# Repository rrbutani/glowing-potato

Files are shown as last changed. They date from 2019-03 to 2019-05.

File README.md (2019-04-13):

# glowing-potato

A work in progress. Still needs a name and a README.

##### Group

The group behind this project consists of:
 - [Blake Martini](https://github.com/Dreadzone345)
 - [Sneha Pendharker](https://github.com/spendharkar)
 - [Sameer Mithani](https://github.com/sameermithani)
 - [Rahul Butani](https://github.com/rrbutani)

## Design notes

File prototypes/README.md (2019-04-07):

## Prototypes:

- Clickwheel (ATQ + wheel on FR-4)
- SD Card (microSD Card pin breakout)
- Buttons (push buttons + diodes on a breadboard; ADC + DIN)
- Display (other ILI9314 w/FPC connector on FR-4)
- VS1053 (Adafruit breakout on a breadboard)

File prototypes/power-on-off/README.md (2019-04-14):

# Power On/Off Prototype

Quick test to see if we can combine a NAND Gate based latching power on/power off circuit with a GPIO pin from a microcontroller.

The latching NAND Gate based circuit is the one described on [this page](http://www.mosaic-industries.com/embedded-systems/microcontroller-projects/electronic-circuits/push-button-switch-turn-on/latching-toggle-power-switch) (the "Press ON - Hold OFF latching circuit" in figure 5).

The goal is to use a GPIO pin to force a power off. If we connect an output pin set to low to the capacitor feeding into the NAND gate, we should immediately power off. If this same pin is in a high-Z state, we _should_ (hopefully - this is the assumption being tested) allow the circuit to operate as normal.

GPIO26 doesn't have a reset state listed on the [ESP32 Pin List](https://www.bitsandparts.eu/documentation/484/esp32_chip_pin_list_en.pdf), which supposedly means it'll be in high-Z on reset (according to [this](https://esp32.com/viewtopic.php?t=1926)).

One big flaw in all this is that the circuit runs off unregulated power because it toggles the enable on the regulator instead of the enable pins on all the ICs (why it does this is a separate thing but the short version is that it seems like a safer way to ensure that we aren't drawing much current when powered off - an important thing when using LiPo cells). This means that we can't connect a GPIO pin to the circuit since doing so would expose the ESP32 to higher voltages than it's rated for (>4.2V for a single cell LiPo).

So we'll settle for not truly being able to turn off the device from the ESP32. This is going to result in a weird user interface where we'll expose a software shutdown option which, after performing the necessary software shutdown routines, instructs the user to power and hold the power button to _truly_ shutdown.

Or we can just go into a soft shutdown state (with a button press triggering a 'boot' up) and hope that the other components aren't drawing too much power and that UVLO will save us (now that we have a UVLO circuit this is something that we can actually maybe count on). Sidenote: UVLO should disengage once charging kicks in as we'd expect.

So now that I've written this, it's become apparent that writing this quick and dirty test would be a bad use of time. So, till next time!

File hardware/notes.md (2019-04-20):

things to keep in mind while routing:
- trace width needs to match the current
- our important signal trace pairs should be the same length (use miter)
- silkscreen labels for parts should be small and close to the actual component
- silkscreen things can't overlap vias or pins
- there are minimum via and trace sizes and also minimum distances between things; use the jlcpcb DRU file and run DRC; eagle will check this stuff for you
- some components have particular recommended layouts (@Blake if you don't have time to route, that's fine but can you point me to the suggested layouts/things to check for the crystal, the regulators, and the VS1053?)
- we want to leave a large space from the antenna to the display connector empty so that the battery can go there; traces are fine here and so are low profile components (*<=1mm*)
- nothing on the top of the PCB where the buttons are (unless they're <1mm, but I doubt we'll have anything)
- ATQ traces are sensitive and need to be away from other things
- the antenna is sensitive and needs to have the surrounding ground place stripped away
- nothing on the top layer where the display is other than the traces
- follow the conventions for silkscreen labels (top left anchor for bottom layer parts, text left to right and top to bottom, 90degrees clockwise for vertical labels)
- don't place components in the area directly above the sd card and the headphone jack and in the same places reflected over the middle of the board; we want to leave some space for the magnets (probably 3 by 6mm, 6 vertically)
- don't move the connectors on the bottom (USB, headphone jack, microSD) or the display connector or it's hole or the CP2102N or the antenna or the buttons or the mounting holes around the board. VS1053 should stay roughly where it is and the esp32 and everything else is fair game to move. battery connector I'm thinking should go below the antenna
- turn off measures and document layers to hide all the alignment stuff (don't remove or move anything already on those layers though)
- we have top and bottom ground planes (remind me: *these need to be connected*); use ratsnest to fill them in and ripup to remove them
- using 0402 for resistors and also 0402 for caps *that aren't special*; so far I've only changed the parts on the first page of the schematic
- save early and often; eagle tends to crash with this board, at least for me
- for trace widths: you have to consider how much current will actually go through a particular trace, not just how much current the part you happen to be connecting at that point will draw
- the buttons' footprint is problematic; it has restrict errors which we can fix later
- inductor footprints as of now are misleading and probably should be updated (they take up more space than just their pads)
- I'm thinking either under the display or where the buttons are for silkscreen art
- we can't do via-in-pins or blind/buried via, I think

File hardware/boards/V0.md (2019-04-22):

## V0: Misc things
 - We're going to use 3x1mm disc magnets. These should be thin enough to put underneath the screen.
 - Here are the numbers on the device thickness:
     + We've got our 1.2mm main PCB in the middle. On the top of the device we've got:
         * the display (2.8mm thick); once we add the magnets and the padding (VHB RP45, 1.1mm), we'll get up to 4mm
         * and on the bottom:
             - the buttons (0.56mm)
             - the 3D printer interfacers (0.24mm)
             - the clickwheel PCB (1.2mm)
             - 1/16th inch acrylic (1.5875mm)
             - vinyl (0.4mm, hopefully)
             - for a total of: ~4mm!
         * If all goes according to plan, we should only go 4mm above the top of the top PCB and the 3D printed top half of the case should be flush with the screen and the top of the clickwheel.
     + On the bottom (below the main PCB) we've got a bunch of components. The notable ones are the headphone jack connector and the XH battery connector. The latter is the tallest of the components and clocks in at 6.1mm (a little disappointing since it's the tallest component by a fair margin, but it's fine - it'll give us more headroom for the battery).
         * The bottom casing will need to extend a little bit past this; hopefully no more than 0.9mm or so.
     + This gives us a total thickness of 0.9mm + 6.1mm + 1.2mm + 4mm or 12.2mm which isn't too shabby.

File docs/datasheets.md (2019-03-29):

IC Docs:
 - [AT42QT2120 Datasheet](https://www.mouser.com/datasheet/2/268/doc9634-1369146.pdf)
 - [VS1053 PCB Layout considerations](http://www.vlsi.fi/fileadmin/app_notes/vs10xxan_layout.pdf)
 - [CP2102N Datasheet](https://www.silabs.com/documents/public/data-sheets/cp2102n-datasheet.pdf)
 - [TPS62240 Datasheet](http://www.ti.com/lit/ds/symlink/tps62240.pdf)
 - [TPS63001 Datasheet](http://www.ti.com/lit/ds/symlink/tps63001.pdf)

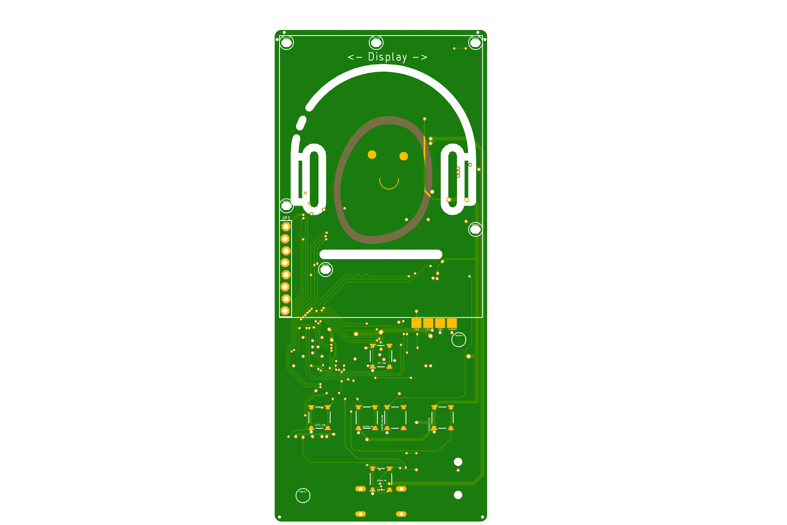
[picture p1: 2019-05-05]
hardware/boards/pico/revA/img/pico-top.png

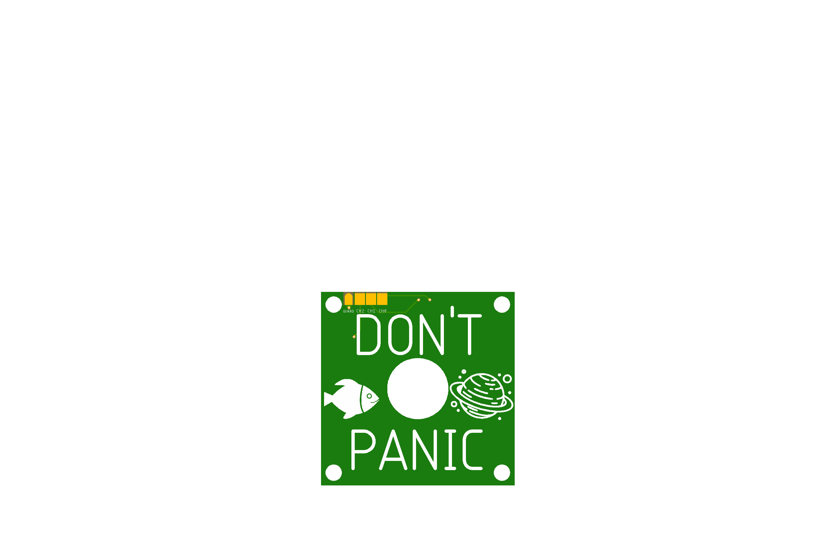
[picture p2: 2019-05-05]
hardware/boards/pico/revA/img/wheel-bottom.png

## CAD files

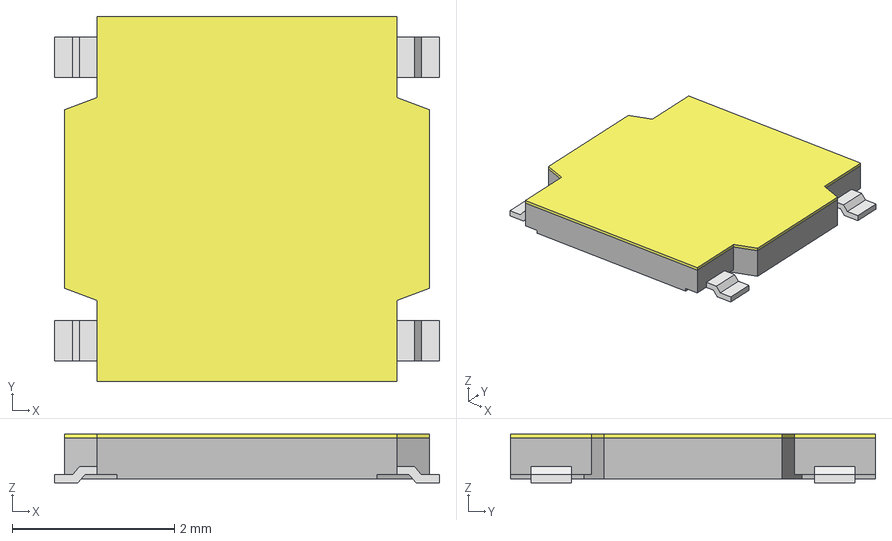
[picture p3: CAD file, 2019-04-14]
hardware/cad/TL3315NF100Q.step
4.75 x 4.50 x 0.6 mm

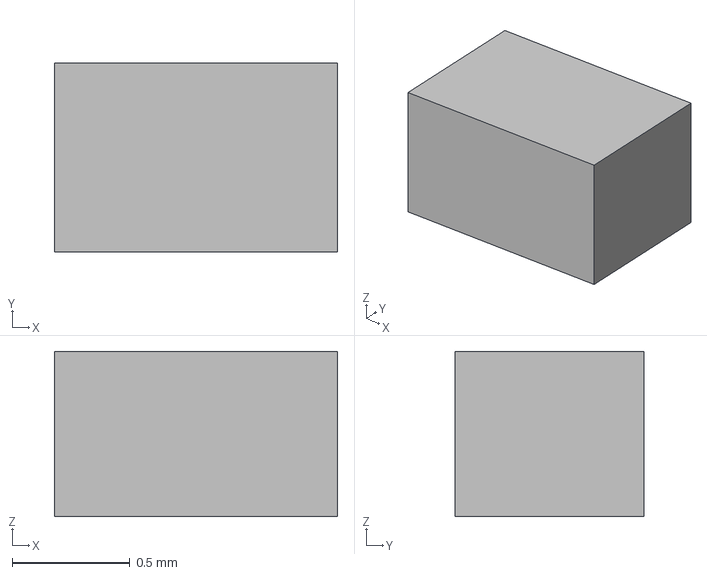
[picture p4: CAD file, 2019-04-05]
hardware/cad/ESD-Diode_On-Semi-ESD5Z5.0T1G.step
1.20 x 0.8 x 0.7 mm

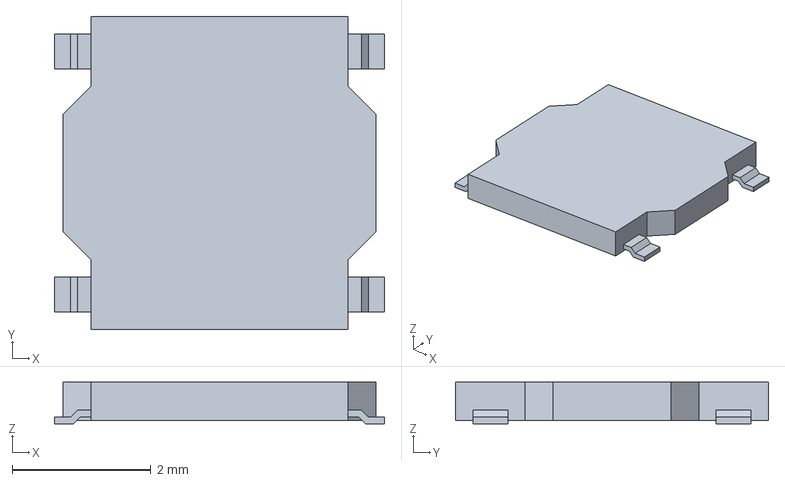
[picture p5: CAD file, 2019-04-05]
hardware/cad/TL3315NF160Q.step
4.75 x 4.50 x 0.6 mm

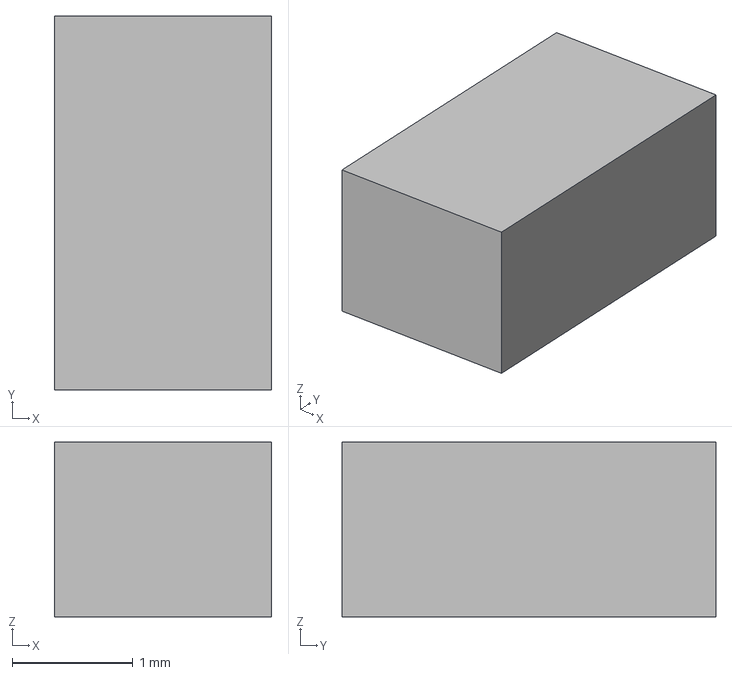
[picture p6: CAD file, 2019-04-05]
hardware/cad/Microchip-MCP73831T-2ATI_2.step
1.80 x 3.10 x 1.45 mm

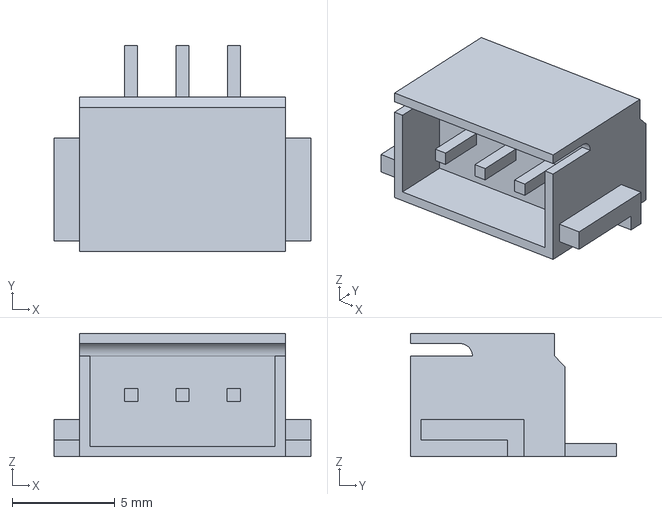
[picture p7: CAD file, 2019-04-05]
hardware/cad/bbf79dea78955795d3a5fd89efec603ff948a89d.step
12.5 x 10.0 x 6.00 mm

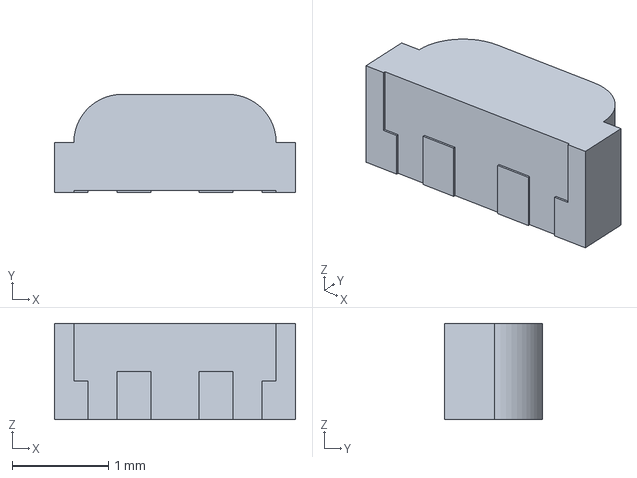
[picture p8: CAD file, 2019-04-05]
hardware/cad/Broadcom-HSMF-C113.step
2.50 x 1.02 x 1.00 mm

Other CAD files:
hardware/cad/Microchip-MCP73831T-2ATI_1.step

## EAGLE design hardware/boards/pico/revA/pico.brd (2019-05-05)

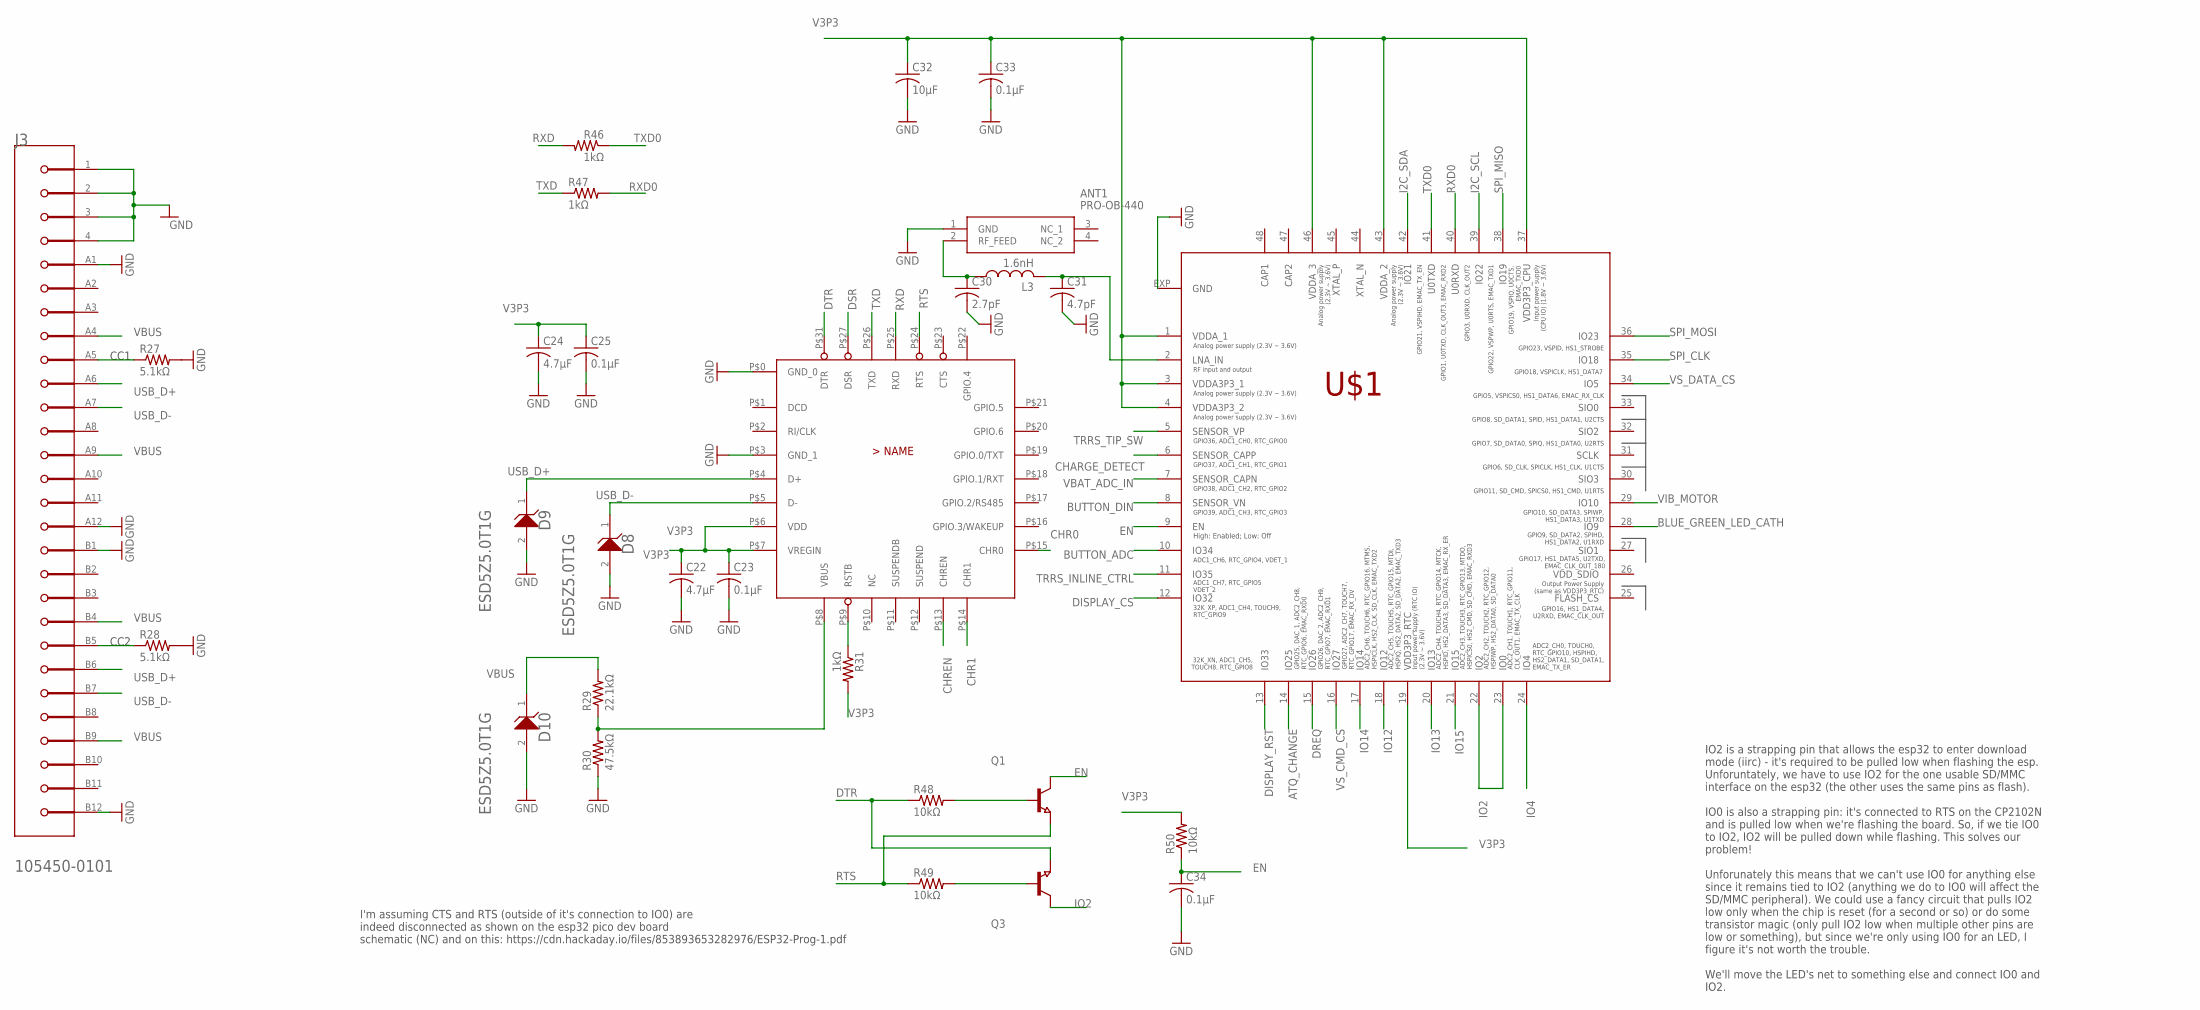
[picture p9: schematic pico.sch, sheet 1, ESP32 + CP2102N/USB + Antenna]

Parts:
ANT1: PRO-OB-440; PRO-OB-440_1
C22, C24: 4.7μF; C0402
C23, C25, C33, C34: 0.1μF; C0402
C30: 2.7pF; C0402
C31: 4.7pF; C0402
C32: 10μF; C0402
D8, D9, D10: ON_SEMICONDUCTOR_ESD5Z5.0T1GON_SEMICONDUCTOR_ESD5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; ON_SEMICONDUCTOR_ESD5Z5.0T1G_0
J3: MOLEX_105450-0101MOLEX_105450-0101_0_0; MOLEX_105450-0101_0
JL: CP2102N-A02-GQFN28; QFN28
L3: 1.6nH; R0402
Q1, Q3: NPN-TRANSISTOR_SOT23; SOT23
R27, R28: 5.1kΩ; R0402
R29: 22.1kΩ; R0402
R30: 47.5kΩ; R0402
R31, R46, R47: 1kΩ; R0402
R48, R49, R50: 10kΩ; R0402
U$1: ESP32-PICO-D4; QFN48

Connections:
ATQ_CHANGE: U$1.14 (IO25); also elsewhere on the board
BLUE_GREEN_LED_CATH: U$1.28 (IO9); also elsewhere on the board
BUTTON_ADC: U$1.10 (IO34); also elsewhere on the board
BUTTON_DIN: U$1.8 (SENSOR_VN); also elsewhere on the board
CHARGE_DETECT: U$1.6 (SENSOR_CAPP); also elsewhere on the board
CHR0: JL.P$15 (CHR0)
CHR1: JL.P$14 (CHR1)
CHREN: JL.P$13 (CHREN)
CP_RSTB: JL.P$9 (RSTB), R31.1
DISPLAY_CS: U$1.12 (IO32); also elsewhere on the board
DISPLAY_RST: U$1.13 (IO33); also elsewhere on the board
DREQ: U$1.15 (IO26); also elsewhere on the board
DSR: JL.P$27 (DSR)
DTR: JL.P$31 (DTR), Q3.2 (E), R48.1
EN: C34.1, Q1.3 (C), R50.1, U$1.9 (EN)
GND: ANT1.1 (GND), C22.2, C23.2, C24.2, C25.2, C30.2, C31.2, C32.2, C33.2, C34.2, D8.2 (A), D9.2 (A), D10.2 (A), J3.1 (MNT_1), J3.2 (MNT_2), J3.3 (MNT_3), J3.4 (MNT_4), J3.A1 (1_GND), J3.A12 (2_GND), J3.B1 (3_GND), J3.B12 (4_GND), JL.P$0 (GND_0), JL.P$3 (GND_1), R27.2, R28.2, R30.1, U$1.EXP (GND); also elsewhere on the board
I2C_SCL: U$1.39 (IO22); also elsewhere on the board
I2C_SDA: U$1.42 (IO21); also elsewhere on the board
IO2: Q3.3 (C), U$1.22 (IO2), U$1.23 (IO0); also elsewhere on the board
IO4: U$1.24 (IO4); also elsewhere on the board
IO12: U$1.18 (IO12); also elsewhere on the board
IO13: U$1.20 (IO13); also elsewhere on the board
IO14: U$1.17 (IO14); also elsewhere on the board
IO15: U$1.21 (IO15); also elsewhere on the board
unnamed: ANT1.2 (RF_FEED), C30.1, L3.1
unnamed: C31.1, L3.2, U$1.2 (LNA_IN)
unnamed: J3.A5 (CC1), R27.1
unnamed: J3.B5 (CC2), R28.1
unnamed: JL.P$8 (VBUS), R29.1, R30.2
unnamed: Q1.1 (B), R48.2
unnamed: Q3.1 (B), R49.2
RTS: JL.P$24 (RTS), Q1.2 (E), R49.1
RXD: JL.P$25 (RXD), R46.2
RXD0: R47.2, U$1.40 (U0RXD)
SPI_CLK: U$1.35 (IO18); also elsewhere on the board
SPI_MISO: U$1.38 (IO19); also elsewhere on the board
SPI_MOSI: U$1.36 (IO23); also elsewhere on the board
TRRS_INLINE_CTRL: U$1.11 (IO35); also elsewhere on the board
TRRS_TIP_SW: U$1.5 (SENSOR_VP); also elsewhere on the board
TXD: JL.P$26 (TXD), R47.1
TXD0: R46.1, U$1.41 (U0TXD)
USB_D+: D9.1 (K), J3.A6 (1_D+), J3.B6 (2_D+), JL.P$4 (D+)
USB_D-: D8.1 (K), J3.A7 (1_D-), J3.B7 (2_D-), JL.P$5 (D-)
V3P3: C22.1, C23.1, C24.1, C25.1, C32.1, C33.1, JL.P$6 (VDD), JL.P$7 (VREGIN), R31.2, R50.2, U$1.1 (VDDA_1), U$1.3 (VDDA3P3_1), U$1.4 (VDDA3P3_2), U$1.19 (VDD3P3_RTC), U$1.37 (VDD3P3_CPU), U$1.43 (VDDA_2), U$1.46 (VDDA_3); also elsewhere on the board
VBAT_ADC_IN: U$1.7 (SENSOR_CAPN); also elsewhere on the board
VBUS: D10.1 (K), J3.A4 (1_VBUS), J3.A9 (2_VBUS), J3.B4 (3_VBUS), J3.B9 (4_VBUS), R29.2; also elsewhere on the board
VIB_MOTOR: U$1.29 (IO10); also elsewhere on the board
VS_CMD_CS: U$1.16 (IO27); also elsewhere on the board
VS_DATA_CS: U$1.34 (IO5); also elsewhere on the board

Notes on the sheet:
CC1
CC2
I'm assuming CTS and RTS (outside of it's connection to IO0) are indeed disconnected as shown on the esp32 pico dev board schematic (NC) and on this: https://cdn.hackaday.io/files/853893653282976/ESP32-Prog-1.pdf
IO2 is a strapping pin that allows the esp32 to enter download mode (iirc) - it's required to be pulled low when flashing the esp. Unforuntately, we have to use IO2 for the one usable SD/MMC interface on the esp32 (the other uses the same pins as flash). IO0 is also a strapping pin: it's connected 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

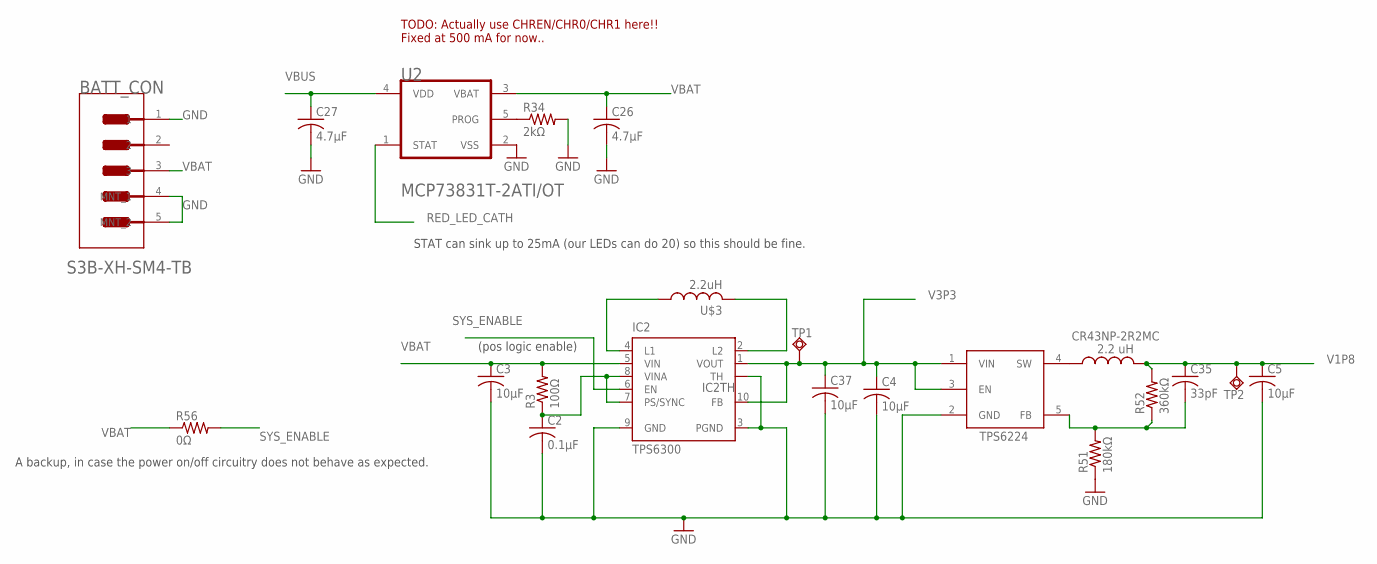
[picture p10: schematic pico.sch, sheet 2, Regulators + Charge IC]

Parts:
BATT_CON: JST_S3B-XH-SM4-TBJST_S3B-XH-SM4-TB_0_0; JST_S3B-XH-SM4-TB_0
C2: 0.1μF; C0402
C3, C4, C5, C37: 10μF; C0402
C26, C27: 4.7μF; C0402
C35: 33pF; C0402
IC2: TPS6300; DRC-S-PVSON-N10
R3: 100Ω; R0402
R34: 2kΩ; R0402
R51: 180kΩ; R0402
R52: 360kΩ; R0402
R56: 0Ω; R0603
TP1, TP2: TPSQTP15SQ; TP15SQ
TPS6224: TPS62240; TSP62240
U2: MICROCHIP_MCP73831T-2ATI-OTMICROCHIP_MCP73831T-2A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; MICROCHIP_MCP73831T-2ATI-OT_1
U$3: 2.2uH; INDUCTOR
U$5: CR43NP-2R2MC; INDUCTOR

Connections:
GND: BATT_CON.1, BATT_CON.4 (MNT_1), BATT_CON.5 (MNT_2), C2.2, C3.2, C4.2, C5.2, C26.2, C27.2, C37.2, IC2.3 (PGND), IC2.9 (GND), IC2.TH, R34.2, R51.1, TPS6224.2 (GND), U2.2 (VSS); also elsewhere on the board
unnamed: C2.1, IC2.7 (PS/SYNC), IC2.8 (VINA), R3.1
unnamed: IC2.2 (L2), U$3.P$2 (2)
unnamed: IC2.4 (L1), U$3.P$1 (1)
unnamed: TPS6224.4 (SW), U$5.P$1 (1)
unnamed: C35.2, R51.2, R52.1, TPS6224.5 (FB)
unnamed: R34.1, U2.5 (PROG)
RED_LED_CATH: U2.1 (STAT); also elsewhere on the board
SYS_ENABLE: IC2.6 (EN), R56.2; also elsewhere on the board
V1P8: C5.1, C35.1, R52.2, TP2.TP, U$5.P$2 (2); also elsewhere on the board
V3P3: C4.1, C37.1, IC2.1 (VOUT), IC2.10 (FB), TP1.TP, TPS6224.1 (VIN), TPS6224.3 (EN); also elsewhere on the board
VBAT: BATT_CON.3, C3.1, C26.1, IC2.5 (VIN), R3.2, R56.1, U2.3 (VBAT); also elsewhere on the board
VBUS: C27.1, U2.4 (VDD); also elsewhere on the board

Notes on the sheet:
TPS6224
TODO: Actually use CHREN/CHR0/CHR1 here!! Fixed at 500 mA for now..
STAT can sink up to 25mA (our LEDs can do 20) so this should be fine.
(pos logic enable)
A backup, in case the power on/off circuitry does not behave as expected.

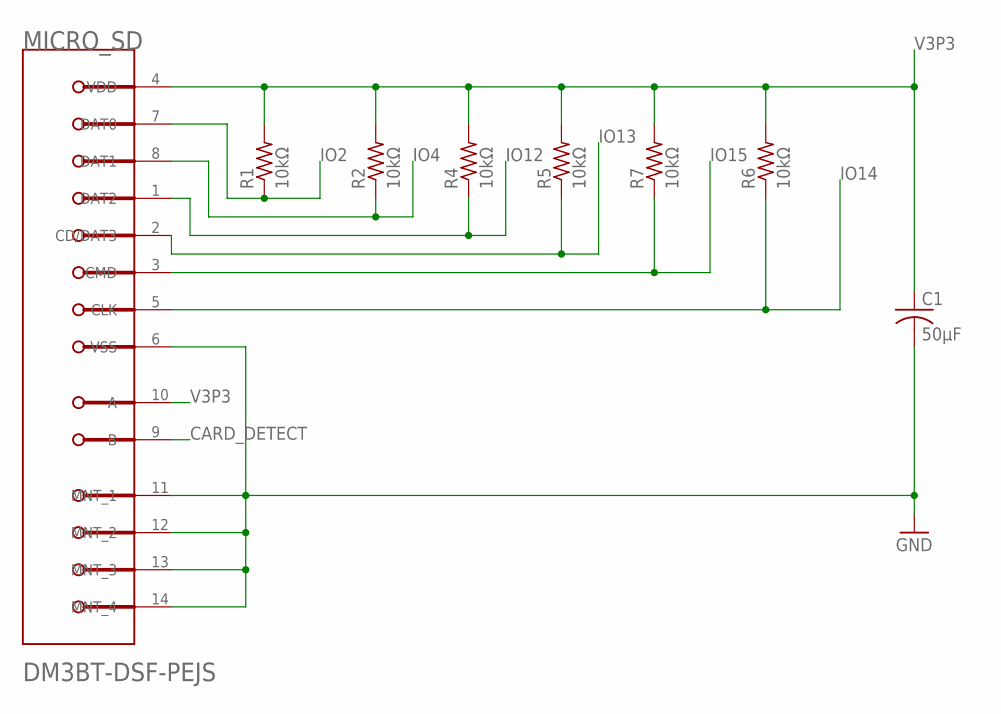
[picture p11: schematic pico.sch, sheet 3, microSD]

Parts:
C1: 50μF; C0402
MICRO_SD: HIROSE_DM3BT-DSF-PEJSHIROSE_DM3BT-DSF-PEJS_0_0; HIROSE_DM3BT-DSF-PEJS_0
R1, R2, R4, R5, R6, R7: 10kΩ; R0402

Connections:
CARD_DETECT: MICRO_SD.9 (B); also elsewhere on the board
GND: C1.2, MICRO_SD.6 (VSS), MICRO_SD.11 (MNT_1), MICRO_SD.12 (MNT_2), MICRO_SD.13 (MNT_3), MICRO_SD.14 (MNT_4); also elsewhere on the board
IO2: MICRO_SD.7 (DAT0), R1.1; also elsewhere on the board
IO4: MICRO_SD.8 (DAT1), R2.1; also elsewhere on the board
IO12: MICRO_SD.1 (DAT2), R4.1; also elsewhere on the board
IO13: MICRO_SD.2 (CD/DAT3), R5.1; also elsewhere on the board
IO14: MICRO_SD.5 (CLK), R6.1; also elsewhere on the board
IO15: MICRO_SD.3 (CMD), R7.1; also elsewhere on the board
V3P3: C1.1, MICRO_SD.4 (VDD), MICRO_SD.10 (A), R1.2, R2.2, R4.2, R5.2, R6.2, R7.2; also elsewhere on the board

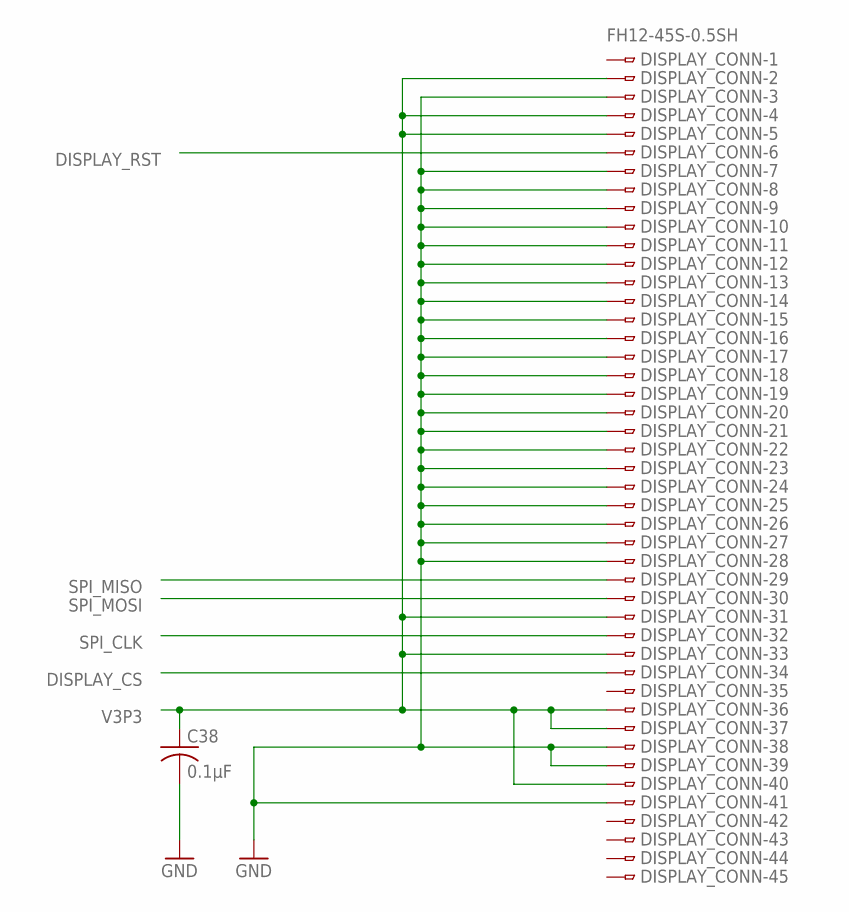
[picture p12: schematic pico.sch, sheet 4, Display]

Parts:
C38: 0.1μF; C0402
DISPLAY_CONN: FH12-45S-0.5SH

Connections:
DISPLAY_CS: DISPLAY_CONN.34; also elsewhere on the board
DISPLAY_RST: DISPLAY_CONN.6; also elsewhere on the board
GND: C38.2, DISPLAY_CONN.3, DISPLAY_CONN.7, DISPLAY_CONN.8, DISPLAY_CONN.9, DISPLAY_CONN.10, DISPLAY_CONN.11, DISPLAY_CONN.12, DISPLAY_CONN.13, DISPLAY_CONN.14, DISPLAY_CONN.15, DISPLAY_CONN.16, DISPLAY_CONN.17, DISPLAY_CONN.18, DISPLAY_CONN.19, DISPLAY_CONN.20, DISPLAY_CONN.21, DISPLAY_CONN.22, DISPLAY_CONN.23, DISPLAY_CONN.24, DISPLAY_CONN.25, DISPLAY_CONN.26, DISPLAY_CONN.27, DISPLAY_CONN.28, DISPLAY_CONN.38, DISPLAY_CONN.39, DISPLAY_CONN.41; also elsewhere on the board
SPI_CLK: DISPLAY_CONN.32; also elsewhere on the board
SPI_MISO: DISPLAY_CONN.29; also elsewhere on the board
SPI_MOSI: DISPLAY_CONN.30; also elsewhere on the board
V3P3: C38.1, DISPLAY_CONN.2, DISPLAY_CONN.4, DISPLAY_CONN.5, DISPLAY_CONN.31, DISPLAY_CONN.33, DISPLAY_CONN.36, DISPLAY_CONN.37, DISPLAY_CONN.40; also elsewhere on the board

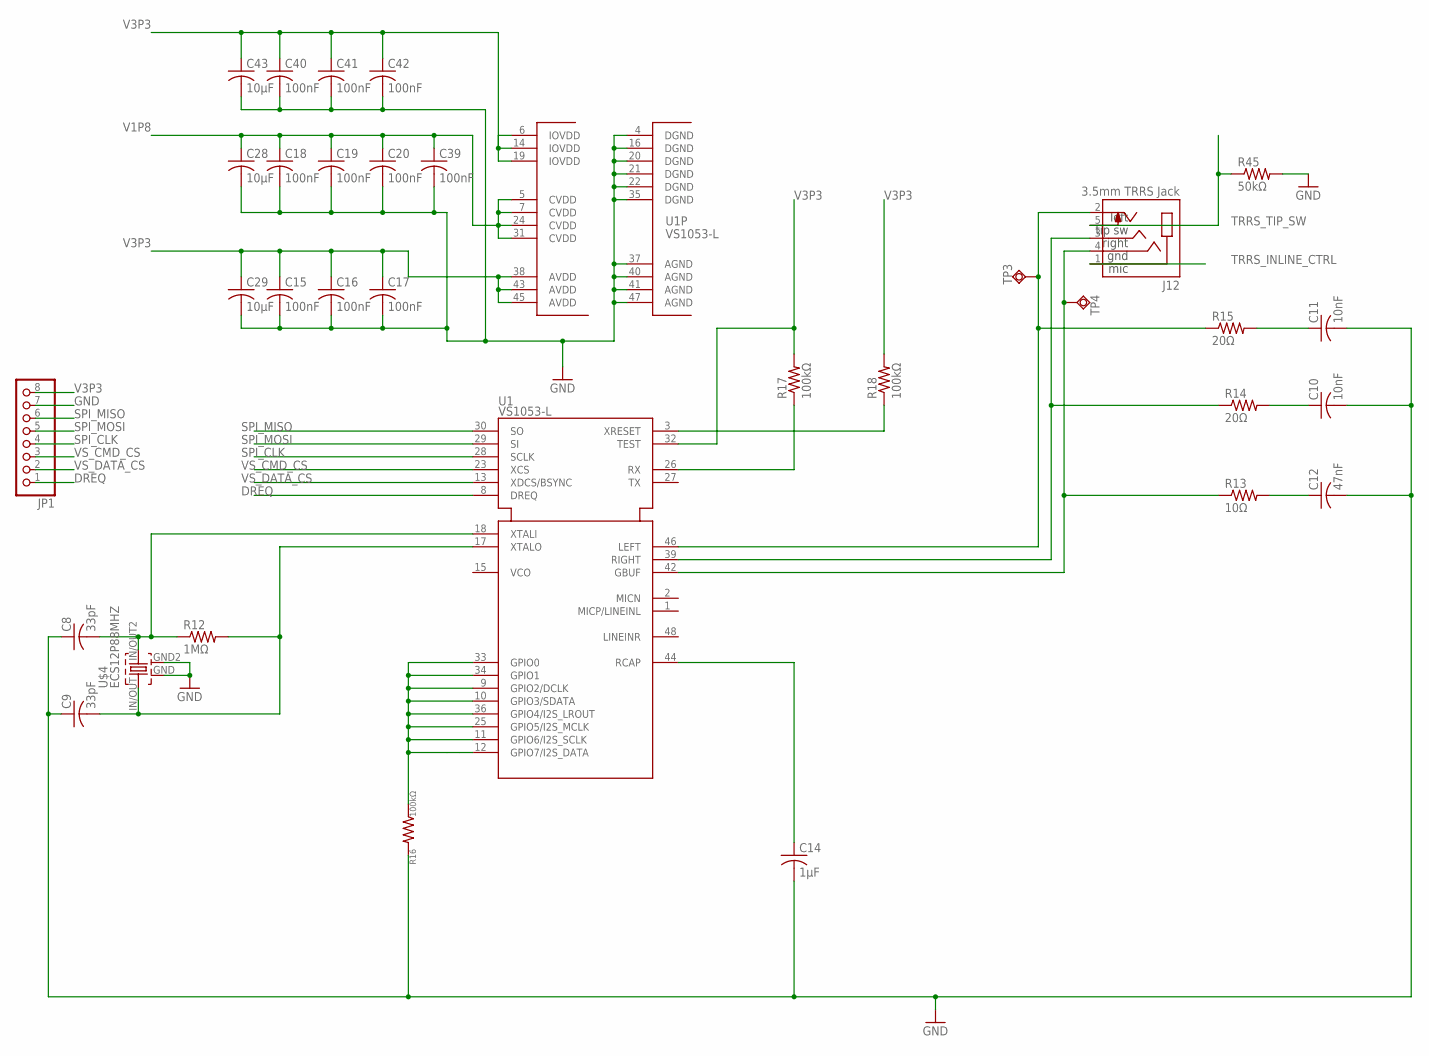
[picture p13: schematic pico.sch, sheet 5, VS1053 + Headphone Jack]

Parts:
C8, C9: 33pF; C0402
C10, C11: 10nF; C0402
C12: 47nF; C0402
C14: 1μF; C0402
C15, C16, C17, C18, C19, C20, C39, C40, C41, C42: 100nF; C0402
C28, C29, C43: 10μF; C0402
J12: 3.5mm TRRS Jack; CUI_SJ-43515TS-SMT
JP1: PINHD-1X8LOCK; 1X08-LOCK
R12: 1MΩ; R0402
R13: 10Ω; R0402
R14, R15: 20Ω; R0402
R16, R17, R18: 100kΩ; R0402
R45: 50kΩ; R0402
TP3, TP4: TPSQTP15SQ; TP15SQ
U1: VS1053-L; LQFP48
U$4: ECS12P88MHZ; ECSCRYSTAL

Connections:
DREQ: JP1.1, U1.8 (DREQ); also elsewhere on the board
GND: C8.1, C9.1, C10.2, C11.2, C12.2, C14.2, C15.2, C16.2, C17.2, C18.2, C19.2, C20.2, C28.2, C29.2, C39.2, C40.2, C41.2, C42.2, C43.2, JP1.7, R16.2, R45.2, U1.4 (DGND), U1.16 (DGND), U1.20 (DGND), U1.21 (DGND), U1.22 (DGND), U1.35 (DGND), U1.37 (AGND), U1.40 (AGND), U1.41 (AGND), U1.47 (AGND), U$4.GND, U$4.GND2; also elsewhere on the board
unnamed: C8.2, R12.1, U1.18 (XTALI), U$4.IN/OUT2
unnamed: C9.2, R12.2, U1.17 (XTALO), U$4.IN/OUT
unnamed: R17.1, U1.26 (RX)
unnamed: C12.1, R13.2
unnamed: C10.1, R14.2
unnamed: C11.1, R15.2
unnamed: C14.1, U1.44 (RCAP)
unnamed: R18.1, U1.3 (XRESET)
unnamed: R16.1, U1.9 (GPIO2/DCLK), U1.10 (GPIO3/SDATA), U1.11 (GPIO6/I2S_SCLK), U1.12 (GPIO7/I2S_DATA), U1.25 (GPIO5/I2S_MCLK), U1.33 (GPIO0), U1.34 (GPIO1), U1.36 (GPIO4/I2S_LROUT)
unnamed: J12.4 (RING2), R13.1, TP4.TP, U1.42 (GBUF)
unnamed: J12.3 (RING1), R14.1, U1.39 (RIGHT)
unnamed: J12.2 (TIP), R15.1, TP3.TP, U1.46 (LEFT)
SPI_CLK: JP1.4, U1.28 (SCLK); also elsewhere on the board
SPI_MISO: JP1.6, U1.30 (SO); also elsewhere on the board
SPI_MOSI: JP1.5, U1.29 (SI); also elsewhere on the board
TRRS_INLINE_CTRL: J12.1 (SLEEVE); also elsewhere on the board
TRRS_TIP_SW: J12.5 (TIP_SWITCH), R45.1; also elsewhere on the board
V1P8: C18.1, C19.1, C20.1, C28.1, C39.1, U1.5 (CVDD), U1.7 (CVDD), U1.24 (CVDD), U1.31 (CVDD); also elsewhere on the board
V3P3: C15.1, C16.1, C17.1, C29.1, C40.1, C41.1, C42.1, C43.1, JP1.8, R17.2, R18.2, U1.6 (IOVDD), U1.14 (IOVDD), U1.19 (IOVDD), U1.32 (TEST), U1.38 (AVDD), U1.43 (AVDD), U1.45 (AVDD); also elsewhere on the board
VS_CMD_CS: JP1.3, U1.23 (XCS); also elsewhere on the board
VS_DATA_CS: JP1.2, U1.13 (XDCS/BSYNC); also elsewhere on the board

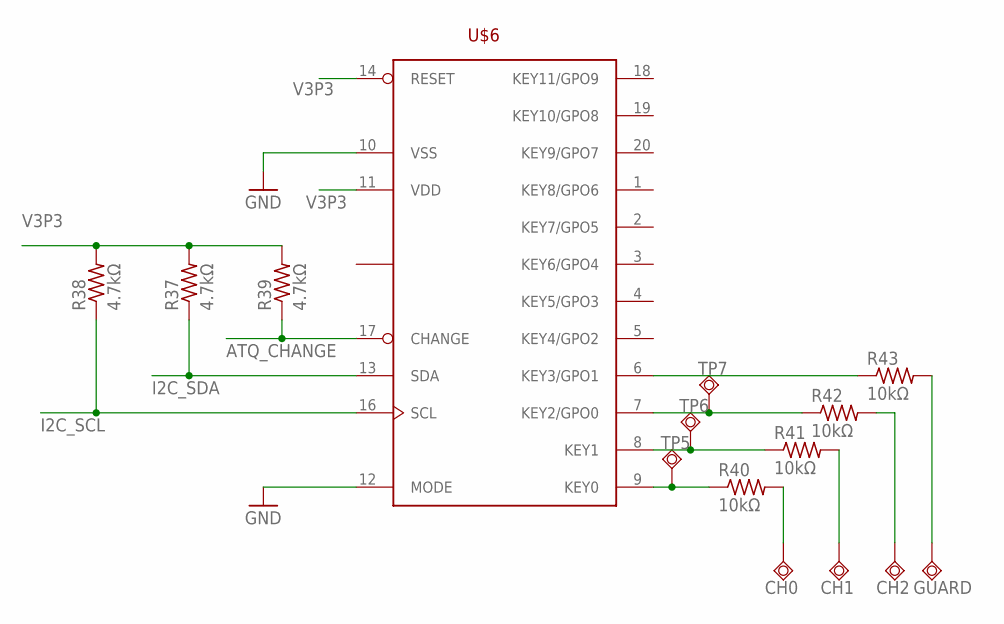
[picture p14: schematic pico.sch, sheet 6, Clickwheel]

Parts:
CH0, CH1, CH2: TPSQTP20SQ; TP20SQ
GUARD: TPSQTP20SQ; TP20SQ
R37, R38, R39: 4.7kΩ; R0402
R40, R41, R42, R43: 10kΩ; R0402
TP5, TP6, TP7: TPSQTP15SQ; TP15SQ
U$6: COMMS-AT42QT2120XU; TSSOP20

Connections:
ATQ_CHANGE: R39.1, U$6.17 (CHANGE); also elsewhere on the board
GND: U$6.10 (VSS), U$6.12 (MODE); also elsewhere on the board
I2C_SCL: R38.1, U$6.16 (SCL); also elsewhere on the board
I2C_SDA: R37.1, U$6.13 (SDA); also elsewhere on the board
unnamed: R40.1, TP5.TP, U$6.9 (KEY0)
unnamed: CH1.TP, R41.2
unnamed: CH2.TP, R42.2
unnamed: R41.1, TP6.TP, U$6.8 (KEY1)
unnamed: R42.1, TP7.TP, U$6.7 (KEY2/GPO0)
unnamed: R43.1, U$6.6 (KEY3/GPO1)
unnamed: CH0.TP, R40.2
unnamed: GUARD.TP, R43.2
V3P3: R37.2, R38.2, R39.2, U$6.11 (VDD), U$6.14 (RESET); also elsewhere on the board

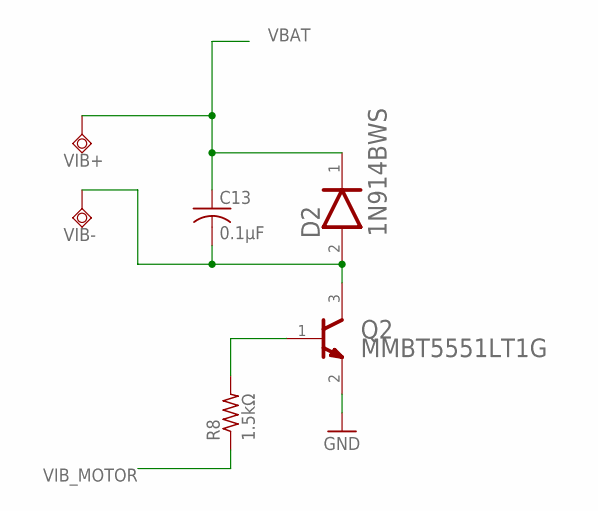
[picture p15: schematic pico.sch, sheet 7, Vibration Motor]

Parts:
C13: 0.1μF; C0402
D2: ON_SEMI_1N914BWSON_SEMI_1N914BWS_0_0; ON_SEMI_1N914BWS_0
Q2: ON_SEMI_MMBT5551LT1GON_SEMI_MMBT5551LT1G_0_0; ON_SEMI_MMBT5551LT1G_0
R8: 1.5kΩ; R0402
VIB+: TPSQTP20SQ; TP20SQ
VIB-: TPSQTP20SQ; TP20SQ

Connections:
GND: Q2.2 (EMITTER); also elsewhere on the board
unnamed: C13.2, D2.2 (ANODE), Q2.3 (COLLECTOR), VIB-.TP
unnamed: Q2.1 (BASE), R8.2
VBAT: C13.1, D2.1 (CATHODE), VIB+.TP; also elsewhere on the board
VIB_MOTOR: R8.1; also elsewhere on the board

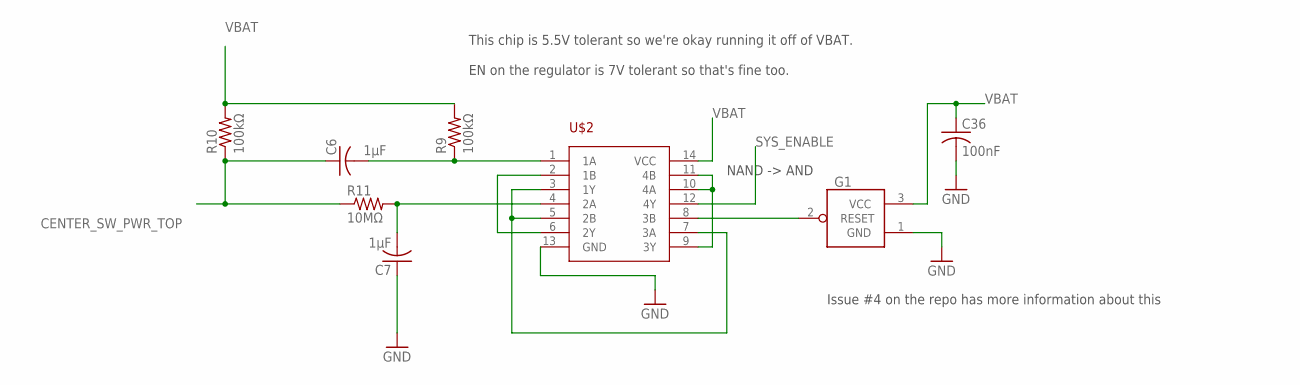
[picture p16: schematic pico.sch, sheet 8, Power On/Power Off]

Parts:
C6, C7: 1μF; C0402
C36: 100nF; C0402
G1: APX809S-31SA; SOT23
R9, R10: 100kΩ; R0402
R11: 10MΩ; R0402
U$2: TOSHIBA-NAND-GATE; TSSOP14

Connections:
CENTER_SW_PWR_TOP: C6.1, R10.1, R11.1; also elsewhere on the board
GND: C7.1, C36.2, G1.1 (GND), U$2.13 (GND); also elsewhere on the board
unnamed: C6.2, R9.1, U$2.1 (1A)
unnamed: U$2.3 (1Y), U$2.5 (2B), U$2.7 (3A)
unnamed: C7.2, R11.2, U$2.4 (2A)
unnamed: U$2.2 (1B), U$2.6 (2Y)
unnamed: U$2.9 (3Y), U$2.10 (4A), U$2.11 (4B)
unnamed: G1.2 (RESET), U$2.8 (3B)
SYS_ENABLE: U$2.12 (4Y); also elsewhere on the board
VBAT: C36.1, G1.3 (VCC), R9.2, R10.2, U$2.14 (VCC); also elsewhere on the board

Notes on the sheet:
This chip is 5.5V tolerant so we're okay running it off of VBAT. EN on the regulator is 7V tolerant so that's fine too.
Issue #4 on the repo has more information about this
NAND -> AND

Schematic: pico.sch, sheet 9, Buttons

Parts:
C21: 0.1μF; C0402
CENTER_SW: E-SWITCH_TL3315NF100QE-SWITCH_TL3315NF100Q_0_0; E-SWITCH_TL3315NF100Q_0
CENTER_SW_PWR: E-SWITCH_TL3315NF100QE-SWITCH_TL3315NF100Q_0_0; E-SWITCH_TL3315NF100Q_0
D3, D4, D5, D6, D7: DIODESOD-523; SOD-523
DOWN_SW: E-SWITCH_TL3315NF160QE-SWITCH_TL3315NF160Q_0_0; E-SWITCH_TL3315NF160Q_0
LEFT_SW: E-SWITCH_TL3315NF160QE-SWITCH_TL3315NF160Q_0_0; E-SWITCH_TL3315NF160Q_0
R19: 155kΩ; R0402
R20: 75kΩ; R0402
R21: 35kΩ; R0402
R22: 15kΩ; R0402
R23, R25: 5kΩ; R0402
R24: 50kΩ; R0402
R26: 10kΩ; R0402
R54: 315kΩ; R0402
RIGHT_SW: E-SWITCH_TL3315NF160QE-SWITCH_TL3315NF160Q_0_0; E-SWITCH_TL3315NF160Q_0
UP_SW: E-SWITCH_TL3315NF160QE-SWITCH_TL3315NF160Q_0_0; E-SWITCH_TL3315NF160Q_0

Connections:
BUTTON_ADC: R19.1, R20.1, R21.1, R22.1, R23.1, R25.2, R54.1; also elsewhere on the board
BUTTON_DIN: C21.2, R24.2; also elsewhere on the board
CARD_DETECT: R54.2; also elsewhere on the board
CENTER_SW_PWR_TOP: CENTER_SW_PWR.1, CENTER_SW_PWR.1-2 (1), CENTER_SW_PWR.2, CENTER_SW_PWR.2-2 (2); also elsewhere on the board
GND: CENTER_SW_PWR.3, CENTER_SW_PWR.3-2 (3), CENTER_SW_PWR.4, CENTER_SW_PWR.4-2 (4), R25.1, R26.1; also elsewhere on the board
unnamed: D4.A, R20.2, UP_SW.3, UP_SW.3-2 (3), UP_SW.4, UP_SW.4-2 (4)
unnamed: D5.A, R21.2, RIGHT_SW.3, RIGHT_SW.3-2 (3), RIGHT_SW.4, RIGHT_SW.4-2 (4)
unnamed: D6.A, DOWN_SW.3, DOWN_SW.3-2 (3), DOWN_SW.4, DOWN_SW.4-2 (4), R22.2
unnamed: CENTER_SW.3, CENTER_SW.3-2 (3), CENTER_SW.4, CENTER_SW.4-2 (4), D7.A, R23.2
unnamed: D3.K (C), D4.K (C), D5.K (C), D6.K (C), D7.K (C), R24.1, R26.2
unnamed: D3.A, LEFT_SW.3, LEFT_SW.3-2 (3), LEFT_SW.4, LEFT_SW.4-2 (4), R19.2
V3P3: C21.1, CENTER_SW.1, CENTER_SW.1-2 (1), CENTER_SW.2, CENTER_SW.2-2 (2), DOWN_SW.1, DOWN_SW.1-2 (1), DOWN_SW.2, DOWN_SW.2-2 (2), LEFT_SW.1, LEFT_SW.1-2 (1), LEFT_SW.2, LEFT_SW.2-2 (2), RIGHT_SW.1, RIGHT_SW.1-2 (1), RIGHT_SW.2, RIGHT_SW.2-2 (2), UP_SW.1, UP_SW.1-2 (1), UP_SW.2, UP_SW.2-2 (2); also elsewhere on the board

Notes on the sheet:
We're going to cheat and introduce a second center switch. It's not optimal but it's a lot less risky than hooking up the real center button to VBAT and hoping that the diode brings the voltage down to spec.

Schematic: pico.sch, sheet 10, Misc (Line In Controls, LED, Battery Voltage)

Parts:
D1: BROADCOM_HSMF-C113BROADCOM_HSMF-C113_0_0; BROADCOM_HSMF-C113_0
R32, R44, R53: 10kΩ; R0402
R33: 5kΩ; R0402
R35: 100Ω; R0402
R36: 50Ω; R0402
R55: 25Ω; R0402

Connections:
BLUE_GREEN_LED_CATH: R36.2, R55.2; also elsewhere on the board
CHARGE_DETECT: R53.1; also elsewhere on the board
GND: R32.1; also elsewhere on the board
unnamed: D1.1 (BLUE_CATHODE), R55.1
unnamed: D1.3 (RED_CATHODE), R35.1
unnamed: D1.4 (GREEN_CATHODE), R36.1
RED_LED_CATH: R35.2, R53.2; also elsewhere on the board
TRRS_INLINE_CTRL: R44.1; also elsewhere on the board
V3P3: D1.2 (COMMON_ANODE), R44.2; also elsewhere on the board
VBAT: R33.2; also elsewhere on the board
VBAT_ADC_IN: R32.2, R33.1; also elsewhere on the board

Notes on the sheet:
Red LED has a 1.9V drop and 20mA, so: 1.4V for 20mA = V / I = R = 1.4V / 20mA = 70 ohms since we don't want to blind people let's call it an even 100
Green LED (AlInGaP Green on the C113) has a drop of about 2.3 volts also on about 20mA. 1.0 volts for 20mA = V / I = R = 1 / 20mA = 50 ohms
Blue has a voltage drop of ~3.7V which is greater than our regulated voltage so we won't bother with a current limiting resistor. Actually we'll add one to protect the esp.
I'm not sure this will work, so leave this resistor off initially/until we've thought it through.
(resistor value here is a guess)

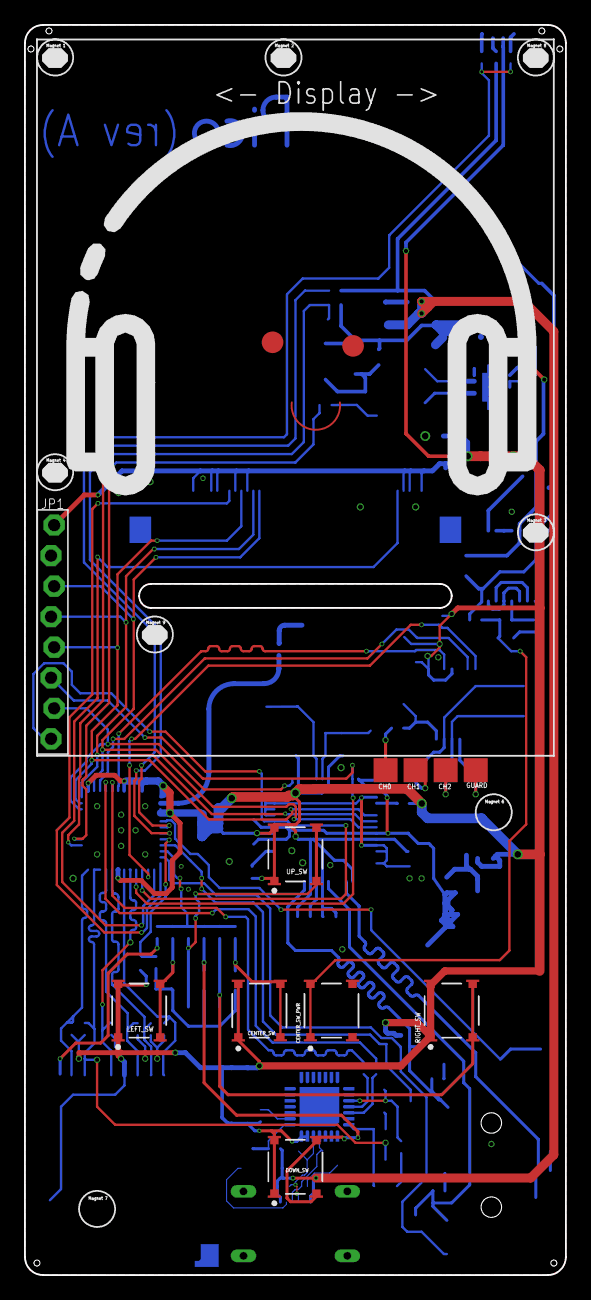
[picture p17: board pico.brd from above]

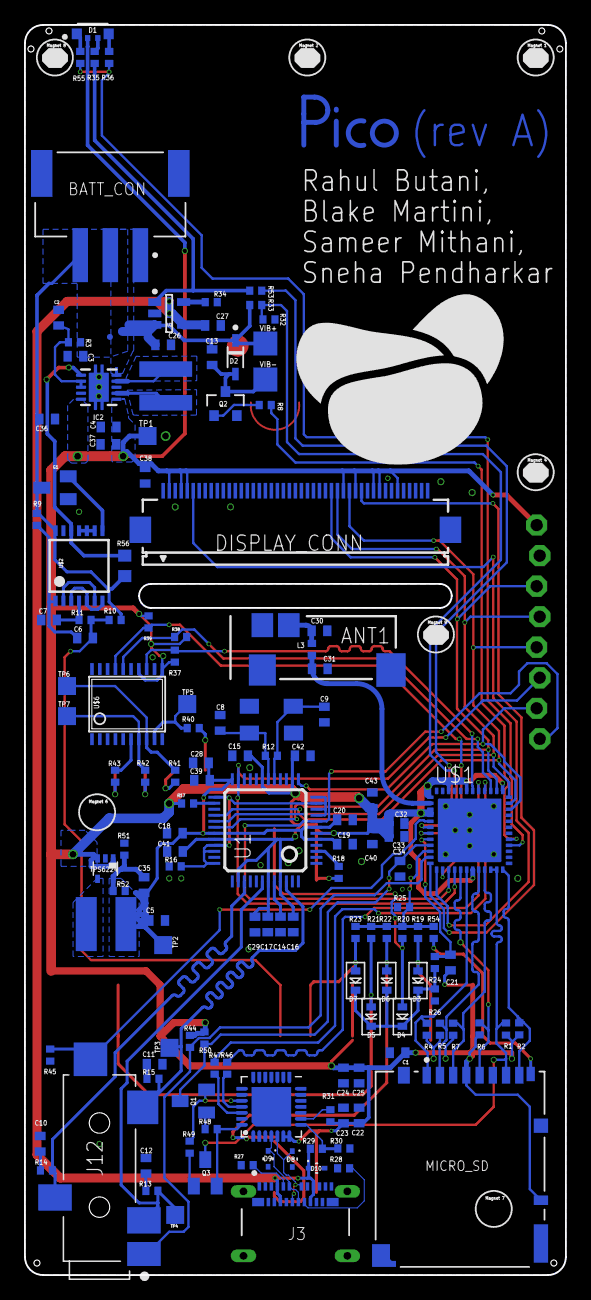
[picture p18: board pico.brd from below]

Board: 2 copper layers, 45.0 x 104.0 mm, 151 parts (140 on the bottom side), 94 nets.

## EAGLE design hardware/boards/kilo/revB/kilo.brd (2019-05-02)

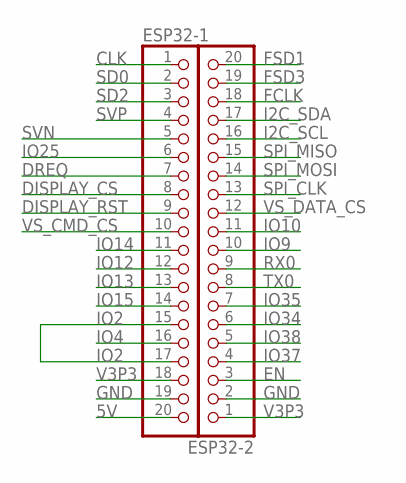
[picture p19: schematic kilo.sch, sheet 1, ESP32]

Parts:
ESP32-1, ESP32-2: PINHD-1X20; 1X20

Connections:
5V: ESP32-1.20
CLK: ESP32-1.1
DISPLAY_CS: ESP32-1.8; also elsewhere on the board
DISPLAY_RST: ESP32-1.9; also elsewhere on the board
DREQ: ESP32-1.7; also elsewhere on the board
EN: ESP32-2.3
FCLK: ESP32-2.18
FSD1: ESP32-2.20
FSD3: ESP32-2.19
GND: ESP32-1.19, ESP32-2.2; also elsewhere on the board
I2C_SCL: ESP32-2.16
I2C_SDA: ESP32-2.17
IO2: ESP32-1.15, ESP32-1.17; also elsewhere on the board
IO4: ESP32-1.16; also elsewhere on the board
IO9: ESP32-2.10; also elsewhere on the board
IO10: ESP32-2.11; also elsewhere on the board
IO12: ESP32-1.12; also elsewhere on the board
IO13: ESP32-1.13; also elsewhere on the board
IO14: ESP32-1.11; also elsewhere on the board
IO15: ESP32-1.14; also elsewhere on the board
IO25: ESP32-1.6; also elsewhere on the board
IO34: ESP32-2.6
IO35: ESP32-2.7
IO37: ESP32-2.4; also elsewhere on the board
IO38: ESP32-2.5; also elsewhere on the board
RX0: ESP32-2.9
SD0: ESP32-1.2
SD2: ESP32-1.3
SPI_CLK: ESP32-2.13; also elsewhere on the board
SPI_MISO: ESP32-2.15; also elsewhere on the board
SPI_MOSI: ESP32-2.14; also elsewhere on the board
SVN: ESP32-1.5
SVP: ESP32-1.4; also elsewhere on the board
TX0: ESP32-2.8
V3P3: ESP32-1.18, ESP32-2.1; also elsewhere on the board
VS_CMD_CS: ESP32-1.10; also elsewhere on the board
VS_DATA_CS: ESP32-2.12; also elsewhere on the board

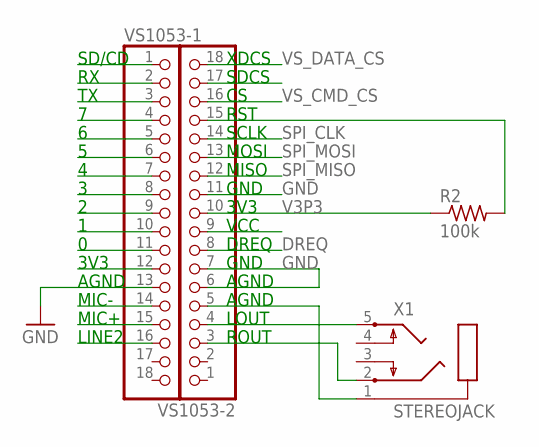
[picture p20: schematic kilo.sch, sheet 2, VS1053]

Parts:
R2: 100k; 0207/10
VS1053-1, VS1053-2: PINHD-1X18; 1X18
X1: STEREOJACK; STX3100

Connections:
DREQ: VS1053-2.8; also elsewhere on the board
GND: VS1053-1.13, VS1053-2.6, VS1053-2.7, VS1053-2.11; also elsewhere on the board
unnamed: VS1053-2.4, X1.5
unnamed: VS1053-2.3, X1.2
unnamed: R2.2, VS1053-2.15
unnamed: VS1053-2.5, X1.1
SPI_CLK: VS1053-2.14; also elsewhere on the board
SPI_MISO: VS1053-2.12; also elsewhere on the board
SPI_MOSI: VS1053-2.13; also elsewhere on the board
V3P3: R2.1, VS1053-2.10; also elsewhere on the board
VS_CMD_CS: VS1053-2.16; also elsewhere on the board
VS_DATA_CS: VS1053-2.18; also elsewhere on the board

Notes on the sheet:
LINE2
MIC+
MIC-
AGND
3V3
SD/CD
ROUT
LOUT
GND
DREQ
VCC
MISO
MOSI
SCLK
RST
SDCS
XDCS


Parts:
DISPLAY: PINHD-1X10; 1X10-BIG

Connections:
DISPLAY_CS: DISPLAY.6; also elsewhere on the board
DISPLAY_RST: DISPLAY.3; also elsewhere on the board
GND: DISPLAY.1; also elsewhere on the board
IO9: DISPLAY.4; also elsewhere on the board
SPI_CLK: DISPLAY.8; also elsewhere on the board
SPI_MISO: DISPLAY.9; also elsewhere on the board
SPI_MOSI: DISPLAY.7; also elsewhere on the board
V3P3: DISPLAY.2, DISPLAY.10; also elsewhere on the board


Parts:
C1: 50uF; E2,5-7
R1, R4, R5, R6, R7, R18: 10k; 0207/10
SDCARD: PINHD-1X10; 1X10-BIG

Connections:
GND: C1.-, SDCARD.8; also elsewhere on the board
IO2: R4.1, SDCARD.9; also elsewhere on the board
IO4: R1.1, SDCARD.10; also elsewhere on the board
IO12: R18.1, SDCARD.3; also elsewhere on the board
IO13: R7.1, SDCARD.4; also elsewhere on the board
IO14: R5.1, SDCARD.7; also elsewhere on the board
IO15: R6.1, SDCARD.5; also elsewhere on the board
V3P3: C1.+, R1.2, R4.2, R5.2, R6.2, R7.2, R18.2, SDCARD.6; also elsewhere on the board

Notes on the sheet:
Card Detect A
Card Detect B
1: DAT2
2: CD/DAT3
3: CMD
4: VDD
5: CLK
6: VSS
7: DAT0
8: DAT1


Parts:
C2, C3, C4, C5, C6: 0.5uF; C025-024X044
R3, R8, R9, R10, R11: 10k; 0207/10
R12, R13, R14, R15, R16: 330; 0207/10
S1, S2, S3, S4, S5: 10-XX; B3F-10XX

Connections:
GND: R12.1, R13.1, R14.1, R15.1, R16.1; also elsewhere on the board
IO10: C5.2, R10.2, R15.2; also elsewhere on the board
IO25: C6.2, R11.2, R16.2; also elsewhere on the board
IO37: C3.2, R8.2, R13.2; also elsewhere on the board
IO38: C2.2, R3.2, R12.2; also elsewhere on the board
unnamed: R3.1, S1.3
unnamed: R8.1, S2.3
unnamed: R9.1, S3.3
unnamed: R10.1, S4.3
unnamed: R11.1, S5.3
SVP: C4.2, R9.2, R14.2; also elsewhere on the board
V3P3: C2.1, C3.1, C4.1, C5.1, C6.1, S1.1 (S), S2.1 (S), S3.1 (S), S4.1 (S), S5.1 (S); also elsewhere on the board

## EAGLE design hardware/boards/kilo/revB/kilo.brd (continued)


Board: 2 copper layers, 100.3 x 100.0 mm, 35 parts (0 on the bottom side), 31 nets.

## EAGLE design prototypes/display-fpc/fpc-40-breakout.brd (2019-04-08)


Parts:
J1: 40PINFPCM4-1734839-0; 4-1734839-0
JP1, JP2: PINHD-1X20/90; 1X20/90

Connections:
1: J1.1 (MSV), JP1.1
2: J1.2 (MS), JP2.1
3: J1.3 (MS), JP1.2
4: J1.4 (MS), JP2.2
5: J1.5 (MS), JP1.3
6: J1.6 (MS), JP2.3
7: J1.7 (MS), JP1.4
8: J1.8 (MS), JP2.4
9: J1.9 (MS), JP1.5
10: J1.10 (MS), JP2.5
11: J1.11 (MS), JP1.6
12: J1.12 (MS), JP2.6
13: J1.13 (MS), JP1.7
14: J1.14 (MS), JP2.7
15: J1.15 (MS), JP1.8
16: J1.16 (MS), JP2.8
17: J1.17 (MS), JP1.9
18: J1.18 (MS), JP2.9
19: J1.19 (MS), JP1.10
20: J1.20 (MS), JP2.10
21: J1.21 (MS), JP1.11
22: J1.22 (MS), JP2.11
23: J1.23 (MS), JP1.12
24: J1.24 (MS), JP2.12
25: J1.25 (MS), JP1.13
26: J1.26 (MS), JP2.13
27: J1.27 (MS), JP1.14
28: J1.28 (MS), JP2.14
29: J1.29 (MS), JP1.15
30: J1.30 (MS), JP2.15
31: J1.31 (MS), JP1.16
32: J1.32 (MS), JP2.16
33: J1.33 (MS), JP1.17
34: J1.34 (MS), JP2.17
35: J1.35 (MS), JP1.18
36: J1.36 (MS), JP2.18
37: J1.37 (MS), JP1.19
38: J1.38 (MS), JP2.19
39: J1.39 (MS), JP1.20
40: J1.40 (MS), JP2.20


Board: 2 copper layers, 53.3 x 56.8 mm, 3 parts (1 on the bottom side), 40 nets.

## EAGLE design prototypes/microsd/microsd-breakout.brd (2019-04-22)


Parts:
JP1: PINHD-1X8/90; 1X08/90
JP2: PINHD-1X2/90; 1X02/90
U$1: MICROSD

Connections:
CLK: JP1.5, U$1.5 (SCLK)
CMD: JP1.3, U$1.3 (DATA_IN)
DAT0: JP1.7, U$1.7 (DATA_OUT)
DAT1: JP1.8, U$1.8 (DAT1)
DAT2: JP1.1, U$1.1 (DAT2)
DAT3: JP1.2, U$1.2 (CS)
unnamed: JP2.1, U$1.CD2 (CARD_DETECT1)
unnamed: JP2.2, U$1.CD1 (CARD_DETECT)
VDD: JP1.4, U$1.4 (VDD)
VSS: JP1.6, U$1.6 (VSS), U$1.MT1 (GND), U$1.MT2 (GND1)


Board: 2 copper layers, 29.0 x 26.7 mm, 3 parts (1 on the bottom side), 10 nets.

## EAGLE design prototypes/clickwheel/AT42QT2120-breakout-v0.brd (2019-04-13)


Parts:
CONTROL: PINHD-1X4/90; 1X04/90
JP1: PINHD-1X4/90; 1X04/90
POWER: PINHD-1X2/90; 1X02/90
U$1: COMMS-AT42QT2120SU; SO20W

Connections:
CHANGE: CONTROL.4, U$1.17 (CHANGE)
GND: POWER.2, U$1.10 (VSS), U$1.12 (MODE)
KEY0: JP1.4, U$1.9 (KEY0)
unnamed: JP1.1, U$1.6 (KEY3/GPO1)
unnamed: JP1.3, U$1.8 (KEY1)
unnamed: JP1.2, U$1.7 (KEY2/GPO0)
RESET: CONTROL.2, U$1.14 (RESET)
SCL: CONTROL.3, U$1.16 (SCL)
SDA: CONTROL.1, U$1.13 (SDA)
V3P3: POWER.1, U$1.11 (VDD)



Board: 2 copper layers, 24.9 x 17.6 mm, 4 parts (3 on the bottom side), 10 nets.

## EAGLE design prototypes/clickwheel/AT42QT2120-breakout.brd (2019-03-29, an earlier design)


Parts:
CLICKWHEEL: PINHD-1X3/90; 1X03/90
DATA: PINHD-1X3/90; 1X03/90
POWER: PINHD-1X2/90; 1X02/90
RESET: PINHD-1X1; 1X01
U$1: COMMS-AT42QT2120SU; SO20W

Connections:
GND: POWER.2, U$1.11 (VDD), U$1.12 (MODE)
unnamed: RESET.1, U$1.14 (RESET)
unnamed: DATA.1, U$1.17 (CHANGE)
unnamed: DATA.2, U$1.16 (SCL)
unnamed: CLICKWHEEL.3, U$1.9 (KEY0)
unnamed: CLICKWHEEL.2, U$1.8 (KEY1)
unnamed: CLICKWHEEL.1, U$1.7 (KEY2/GPO0)
unnamed: DATA.3, U$1.13 (SDA)
V3P3: POWER.1, U$1.10 (VSS)



Board: 2 copper layers, 26.6 x 16.2 mm, 5 parts (2 on the bottom side), 9 nets.

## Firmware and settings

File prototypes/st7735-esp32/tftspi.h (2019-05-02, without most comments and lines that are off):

#define _TFTSPI_H_
#include "tftspi.h"
#include "spi_master_lobo.h"
#include "sdkconfig.h"
#include "stmpe610.h"
#define TOUCH_TYPE_NONE		0
#define TOUCH_TYPE_XPT2046	1
#define TOUCH_TYPE_STMPE610	2
#define TP_CALX_XPT2046		7472920
#define TP_CALY_XPT2046		122224794
#define TP_CALX_STMPE610	21368532
#define TP_CALY_STMPE610	11800144
#define PORTRAIT	0
#define LANDSCAPE	1
#define PORTRAIT_FLIP	2
#define LANDSCAPE_FLIP	3
#define DISP_TYPE_ILI9341	0
#define DISP_TYPE_ILI9488	1
#define DISP_TYPE_ST7789V	2
#define DISP_TYPE_ST7735	3
#define DISP_TYPE_ST7735R	4
#define DISP_TYPE_ST7735B	5
#define DISP_TYPE_MAX		6
#if CONFIG_EXAMPLE_DISPLAY_TYPE == 1
#define DEFAULT_DISP_TYPE           DISP_TYPE_ST7789V
#define DEFAULT_TFT_DISPLAY_WIDTH   240
#define DEFAULT_TFT_DISPLAY_HEIGHT  320
#define DISP_COLOR_BITS_24          0x66
#define DEFAULT_GAMMA_CURVE         0
#define DEFAULT_SPI_CLOCK           26000000
#define TFT_INVERT_ROTATION         0
#define TFT_INVERT_ROTATION1        1
#define TFT_RGB_BGR                 0x00
#define USE_TOUCH	TOUCH_TYPE_NONE
#define PIN_NUM_MISO 19		// SPI MISO
#define PIN_NUM_MOSI 23		// SPI MOSI
#define PIN_NUM_CLK  18		// SPI CLOCK pin
#define PIN_NUM_CS   32		// Display CS pin
#define PIN_NUM_DC   21		// Display command/data pin
#define PIN_NUM_TCS   0		// Touch screen CS pin
#define PIN_NUM_RST  33  	// GPIO used for RESET control
#define PIN_NUM_BCKL  5     // GPIO used for backlight control
#define PIN_BCKL_ON   0     // GPIO value for backlight ON
#define PIN_BCKL_OFF  1     // GPIO value for backlight OFF
#elif CONFIG_EXAMPLE_DISPLAY_TYPE == 2
#define DEFAULT_DISP_TYPE   DISP_TYPE_ILI9341
#define DEFAULT_TFT_DISPLAY_WIDTH   240
#define DEFAULT_TFT_DISPLAY_HEIGHT  320
#define DISP_COLOR_BITS_24          0x66
#define DEFAULT_GAMMA_CURVE         0
#define DEFAULT_SPI_CLOCK           26000000
#define TFT_INVERT_ROTATION         0
#define TFT_INVERT_ROTATION1        0
#define TFT_RGB_BGR                 0x08
#define USE_TOUCH                   TOUCH_TYPE_STMPE610
#define PIN_NUM_MISO 19		// SPI MISO
#define PIN_NUM_MOSI 18		// SPI MOSI
#define PIN_NUM_CLK  5		// SPI CLOCK pin
#define PIN_NUM_CS   15		// Display CS pin
#define PIN_NUM_DC   33		// Display command/data pin
#define PIN_NUM_TCS  32		// Touch screen CS pin (NOT used if USE_TOUCH=0)
#define PIN_NUM_RST  0  	// GPIO used for RESET control (#16)
#define PIN_NUM_BCKL 0  	// GPIO used for backlight control
#define PIN_BCKL_ON  0  	// GPIO value for backlight ON
#define PIN_BCKL_OFF 1  	// GPIO value for backlight OFF
#elif CONFIG_EXAMPLE_DISPLAY_TYPE == 3
#define DEFAULT_DISP_TYPE   DISP_TYPE_ILI9341
#define DEFAULT_TFT_DISPLAY_WIDTH   320
#define DEFAULT_TFT_DISPLAY_HEIGHT  240
#define DISP_COLOR_BITS_24          0x66
#define DEFAULT_GAMMA_CURVE         0
#define DEFAULT_SPI_CLOCK           26000000
#define TFT_INVERT_ROTATION         0
#define TFT_INVERT_ROTATION1        0
#define TFT_INVERT_ROTATION2        1   // Adapte M5Stack TFT
#define TFT_RGB_BGR                 0x08
#define USE_TOUCH                   TOUCH_TYPE_NONE
#define PIN_NUM_MISO 19		// SPI MISO
#define PIN_NUM_MOSI 23		// SPI MOSI
#define PIN_NUM_CLK  18		// SPI CLOCK pin
#define PIN_NUM_CS   14		// Display CS pin
#define PIN_NUM_DC   27		// Display command/data pin
#define PIN_NUM_TCS  0		// Touch screen CS pin (NOT used if USE_TOUCH=0)
#define PIN_NUM_RST  33  	// GPIO used for RESET control (#16)
#define PIN_NUM_BCKL 32  	// GPIO used for backlight control
#define PIN_BCKL_ON  1  	// GPIO value for backlight ON
#define PIN_BCKL_OFF 0  	// GPIO value for backlight OFF
#else
#define DISP_COLOR_BITS_24	0x66
#define TFT_INVERT_ROTATION 0
#define TFT_INVERT_ROTATION1 1
#define TFT_RGB_BGR 0x08
#define PIN_NUM_MISO 19		// SPI MISO
#define PIN_NUM_MOSI 23		// SPI MOSI
#define PIN_NUM_CLK  18		// SPI CLOCK pin
#define PIN_NUM_CS   32		// Display CS pin
#define PIN_NUM_DC    9		// Display command/data pin
#define PIN_NUM_TCS  25		// Touch screen CS pin (NOT used if USE_TOUCH=0)
#define PIN_NUM_RST  0  	// GPIO used for RESET control
#define PIN_NUM_BCKL 0  	// GPIO used for backlight control
#define PIN_BCKL_ON  0  	// GPIO value for backlight ON
#define PIN_BCKL_OFF 1  	// GPIO value for backlight OFF
#define USE_TOUCH	TOUCH_TYPE_NONE
#define DEFAULT_TFT_DISPLAY_WIDTH  128
#define DEFAULT_TFT_DISPLAY_HEIGHT 160
#define DEFAULT_GAMMA_CURVE 0
#define DEFAULT_SPI_CLOCK   26000000
#define DEFAULT_DISP_TYPE   DISP_TYPE_ST7735R
#endif  // CONFIG_EXAMPLE_ESP_WROVER_KIT
extern uint8_t gray_scale;
extern uint32_t max_rdclock;
extern int _width;
extern int _height;
extern uint8_t tft_disp_type;
extern spi_lobo_device_handle_t disp_spi;
extern spi_lobo_device_handle_t ts_spi;
typedef struct __attribute__((__packed__)) {
	uint8_t r;
	uint8_t g;
	uint8_t b;
} color_t ;
#define TFT_INVOFF     0x20
#define TFT_INVONN     0x21
#define TFT_DISPOFF    0x28
#define TFT_DISPON     0x29
#define TFT_MADCTL	   0x36
#define TFT_PTLAR 	   0x30
#define TFT_ENTRYM 	   0xB7
#define TFT_CMD_NOP			0x00
#define TFT_CMD_SWRESET		0x01
#define TFT_CMD_RDDID		0x04
#define TFT_CMD_RDDST		0x09
#define TFT_CMD_SLPIN		0x10
#define TFT_CMD_SLPOUT		0x11
#define TFT_CMD_PTLON		0x12
#define TFT_CMD_NORON		0x13
#define TFT_CMD_RDMODE		0x0A
#define TFT_CMD_RDMADCTL	0x0B
#define TFT_CMD_RDPIXFMT	0x0C
#define TFT_CMD_RDIMGFMT	0x0D
#define TFT_CMD_RDSELFDIAG  0x0F
#define TFT_CMD_GAMMASET	0x26
#define TFT_CMD_FRMCTR1		0xB1
#define TFT_CMD_FRMCTR2		0xB2
#define TFT_CMD_FRMCTR3		0xB3
#define TFT_CMD_INVCTR		0xB4
#define TFT_CMD_DFUNCTR		0xB6
#define TFT_CMD_PWCTR1		0xC0
#define TFT_CMD_PWCTR2		0xC1
#define TFT_CMD_PWCTR3		0xC2
#define TFT_CMD_PWCTR4		0xC3
#define TFT_CMD_PWCTR5		0xC4
#define TFT_CMD_VMCTR1		0xC5
#define TFT_CMD_VMCTR2		0xC7
#define TFT_CMD_RDID1		0xDA
#define TFT_CMD_RDID2		0xDB
#define TFT_CMD_RDID3		0xDC
#define TFT_CMD_RDID4		0xDD
#define TFT_CMD_GMCTRP1		0xE0
#define TFT_CMD_GMCTRN1		0xE1
#define TFT_CMD_POWERA		0xCB
#define TFT_CMD_POWERB		0xCF
#define TFT_CMD_POWER_SEQ	0xED
#define TFT_CMD_DTCA		0xE8
#define TFT_CMD_DTCB		0xEA
#define TFT_CMD_PRC			0xF7
#define TFT_CMD_3GAMMA_EN	0xF2
#define ST_CMD_VCOMS       0xBB
#define ST_CMD_FRCTRL2      0xC6
#define ST_CMD_PWCTR1		0xD0
#define ST7735_FRMCTR1 0xB1
#define ST7735_FRMCTR2 0xB2
#define ST7735_FRMCTR3 0xB3
#define ST7735_INVCTR  0xB4
#define ST7735_DISSET5 0xB6
#define ST7735_PWCTR1  0xC0
#define ST7735_PWCTR2  0xC1
#define ST7735_PWCTR3  0xC2
#define ST7735_PWCTR4  0xC3
#define ST7735_PWCTR5  0xC4
#define ST7735_VMCTR1  0xC5
#define ST7735_RDID1   0xDA
#define ST7735_RDID2   0xDB
#define ST7735_RDID3   0xDC
#define ST7735_RDID4   0xDD
#define ST7735_NOP     0x00
#define ST7735_SWRESET 0x01
#define ST7735_RDDID   0x04
#define ST7735_RDDST   0x09
#define ST7735_SLPIN   0x10
#define ST7735_SLPOUT  0x11
#define ST7735_PTLON   0x12
#define ST7735_NORON   0x13
#define ST7735_PWCTR6  0xFC
#define ST7735_GMCTRP1 0xE0
#define ST7735_GMCTRN1 0xE1
#define MADCTL_MY  0x80
#define MADCTL_MX  0x40
#define MADCTL_MV  0x20
#define MADCTL_ML  0x10
#define MADCTL_MH  0x04
#define TFT_CASET		0x2A
#define TFT_PASET		0x2B
#define TFT_RAMWR		0x2C
#define TFT_RAMRD		0x2E
#define TFT_CMD_PIXFMT	0x3A
#define TFT_CMD_DELAY	0x80
static const uint8_t ST7789V_init[] = {
#if PIN_NUM_RST
  15,                   					        // 15 commands in list
#else
  16,                   					        // 16 commands in list
  TFT_CMD_SWRESET, TFT_CMD_DELAY,					//  1: Software reset, no args, w/delay
  200,												//     200 ms delay
#endif
  TFT_CMD_FRMCTR2, 5, 0x0c, 0x0c, 0x00, 0x33, 0x33,
  TFT_ENTRYM, 1, 0x45,
  ST_CMD_VCOMS, 1, 0x2B,
  TFT_CMD_PWCTR1, 1, 0x2C,
  TFT_CMD_PWCTR3, 2, 0x01, 0xff,
  TFT_CMD_PWCTR4, 1, 0x11,
  TFT_CMD_PWCTR5, 1, 0x20,
  ST_CMD_FRCTRL2, 1, 0x0f,
  ST_CMD_PWCTR1, 2, 0xA4, 0xA1,
  TFT_CMD_GMCTRP1, 14, 0xD0, 0x00, 0x05, 0x0E, 0x15, 0x0D, 0x37, 0x43, 0x47, 0x09, 0x15, 0x12, 0x16, 0x19,
  TFT_CMD_GMCTRN1, 14, 0xD0, 0x00, 0x05, 0x0D, 0x0C, 0x06, 0x2D, 0x44, 0x40, 0x0E, 0x1C, 0x18, 0x16, 0x19,
  TFT_MADCTL, 1, (MADCTL_MX | TFT_RGB_BGR),			// Memory Access Control (orientation)
  TFT_CMD_PIXFMT, 1, DISP_COLOR_BITS_24,            // *** INTERFACE PIXEL FORMAT: 0x66 -> 18 bit; 0x55 -> 16 bit
  TFT_CMD_SLPOUT, TFT_CMD_DELAY, 120,				//  Sleep out,	//  120 ms delay
  TFT_DISPON, TFT_CMD_DELAY, 120,
};
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

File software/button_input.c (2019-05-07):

/* GPIO Example

   This example code is in the Public Domain (or CC0 licensed, at your option.)

   Unless required by applicable law or agreed to in writing, this
   software is distributed on an "AS IS" BASIS, WITHOUT WARRANTIES OR
   CONDITIONS OF ANY KIND, either express or implied.
*/
#include <stdio.h>
#include <string.h>
#include <stdlib.h>
#include "freertos/FreeRTOS.h"
#include "freertos/task.h"
#include "freertos/queue.h"
#include "driver/gpio.h"

/**
 * inputs are 
 * GPIO 37 = up button 
 * GPIO 10 = down button
 * GPIO 36 = left button
 * GPIO 25 = right button
 * GPIO 38 = center button
 */

enum in{
    up,
    down,
    left,
    right,
    center,
    song_end
}inputs;

#define GPIO_INPUT_IO_0 37
#define GPIO_INPUT_IO_1 10
#define GPIO_INPUT_IO_2 36
#define GPIO_INPUT_IO_3 25
#define GPIO_INPUT_IO_4 38
#define GPIO_INPUT_PIN_SEL ((1ULL<<GPIO_INPUT_IO_0) | (1ULL<<GPIO_INPUT_IO_1) | (1ULL<<GPIO_INPUT_IO_2) | (1ULL<<GPIO_INPUT_IO_3) | (1ULL<<GPIO_INPUT_IO_4));

#define ESP_INTR_FLAG_DEFAULT 0

static xQueueHandle gpio_evt_queue = NULL;

static void IRAM_ATTR gpio_isr_handler(void* arg)
{
    enum in button_num = (enum in) arg;
    xQueueSendFromISR(gpio_evt_queue, &button_num, NULL);   //put into queue 
}

#define track_count 20

uint8_t changeState = 0;

static void gpio_task_example(void* arg)
{
    enum in io_num;
    for(;;) {
        if(xQueueReceive(gpio_evt_queue, &io_num, portMAX_DELAY)) {
            //depending on what state is and what button was pressed, may need to change state 
            switch(state){
                case menu: 
                if(io_num == up){
                    data.menu.idx = (data.memu.idx - 1) % track_count;
                    //draw_menu - for lcd
                } else if(io_num == down){
                    data.menu.idx = (data.menu.idx + 1) % track_count;
                    //draw_menu - for lcd
                } else if(io_num == right){
                    //draw_playing(idx, true) - for lcd
                    data.play.play_pause = 1;
                    changeState = 1;
                    //playing(idx, track, data.play.play_pause) - for VS1053
                } else if(io_num == left | io_num == center){
                    //draw_menu(idx) - for lcd
                }
                break;

                case playing:
                if(io_num == center){
                    data.play.play_pause = (!data.play.play_pause);
                    //draw_playing(idx, data.play.play_pause) - for lcd
                    //playing(idx, track, data.play.play_pause) - for VS1053
                } else if(io_num == left){
                    //end_song() - for VS1053
                    //draw_menu - for lcd
                    changeState = 1;
                } else if(io_num == song_end){
                    //draw_menu - for lcd
                    changeState = 1;
                } else if(io_num == up | io_num == down | io_num == right){
                    //playing(idx, track, data.play.play_pause) - for VS1053
                    //don't think we have to draw screen again? 
                }
                breakl
            }
            if(changeState){
                if(state == menu){
                    state = playing;
                } else{
                    state = menu;
                }
            }
            //printf("GPIO[%d] intr, val: %d\n", io_num, gpio_get_level(io_num));
        }
    }
}

static state;
static state_data;

union data{
    struct menu{
        int32_t idx;
    }menu;
    struct play{
        int32_t idx;
        bool play_pause;    //1 for playing, 0 for pause
    }play;
}data;

enum state_machine{
    menu,
    playing
}state;

void app_main()
{   
    gpio_config_t io_conf;
    io_conf.intr_type = GPIO_PIN_POSEDGE;
    io_conf.mode = GPIO_MODE_INPUT;
    io_conf.pin_bit_mask = GPIO_INPUT_PIN_SEL;
    io_conf.pull_down_en = 0;
    io_conf.pull_up_en = 0; 
    gpio_config(&io_conf);      //configure gpio with settings 

    //interrupt of rising edge
    io_conf.intr_type = GPIO_PIN_INTR_POSEDGE;          //should this be GPIO_PIN_POSEDGE???

    //create a queue to handle gpio event from isr
    gpio_evt_queue = xQueueCreate(10, sizeof(uint32_t));    //creates a queue of 10 uint32_t variables
    //start gpio task

    xTaskCreate(gpio_task_example, "gpio_task_example", 2048, NULL, 10, NULL);

    //install gpio isr handler service, allows per pin gpio interrupt handlers 
    gpio_install_isr_service(ESP_INTR_FLAG_DEFAULT);
    //hook isr handler for specific gpio pin
    gpio_isr_handler_add(GPIO_INPUT_IO_0, gpio_isr_handler, (void*) up);
    gpio_isr_handler_add(GPIO_INPUT_IO_1, gpio_isr_handler, (void*) down);
    gpio_isr_handler_add(GPIO_INPUT_IO_2, gpio_isr_handler, (void*) left);
    gpio_isr_handler_add(GPIO_INPUT_IO_3, gpio_isr_handler, (void*) right);
    gpio_isr_handler_add(GPIO_INPUT_IO_4, gpio_isr_handler, (void*) center);

    while(1) {
        vTaskDelay(1000 / portTICK_RATE_MS);        //just to slow it down
    }
}

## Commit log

2019-03-15 AT42QT2120 eagle library: still need to add the standalone device
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2019-03-25 hw: first pass at an esp32 part
2019-03-28 lab07: a draft
    [Draft0.brd, Draft0.sch]
2019-03-28 added vs1053 pcb considerations
2019-03-29 Power regulator added
    [power.sch]
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2019-03-29 lab07: pre-checkout? not proud but it's what we sbumitted
    [Draft0.brd, Draft0.sch]
2019-03-29 a wheel prototype!
    [AT42QT2120-breakout.brd, wheel.brd, wheel.sch]
2019-04-01 VS1053 schematic
    I left the UART and board lines as open wires
    [VS1053 hardware.sch]
2019-04-04 updated motor
    [Draft0.brd, Draft0.sch]
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2019-04-04 added header for motor
    [Draft0.sch]
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2019-04-05 updated screen
    [Draft0.sch]
2019-04-05 screen fixes
    [Draft0.sch]
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2019-04-05 start our CAD collection
    [Broadcom-HSMF-C113.step, Microchip-MCP73831T-2ATI_1.step, Microchip-MCP73831T-2ATI_2.step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]
2019-04-05 our very flat switch
    [TL3315NF160Q.step]
2019-04-05 add ESD protection diode
    [ESD-Diode_On-Semi-ESD5Z5.0T1G.step]
2019-04-05 checkpoint: USB
    [V0.brd, V0.sch]
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2019-04-05 checkpoint: LED, battery voltage circuit, charge IC, half of the CP2102N
    [V0.brd, V0.sch]
2019-04-05 checkpoint: power on and off circuit
    [V0.brd, V0.sch]
2019-04-05 misc VS1053 fixes + fix/wire ATQ
    [V0.brd, V0.sch]
2019-04-05 inline + tip switch (bad) + ??
    [V0.brd, V0.sch]
2019-04-05 antenna and its very specific friends
    [V0.brd, V0.sch]
2019-04-05 added testpads
    [Draft0.sch, V0.brd, V0.sch]
2019-04-05 just the pinmap left!!
    [V0.brd, V0.sch]
2019-04-05 schematic: done!?
    [V0.brd, V0.sch]
2019-04-05 minor fixes: this is an adjustable 1.8V regulator..
    [V0.brd, V0.sch]
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2019-04-08 update ATQ breakouts
    [AT42QT2120-breakout-v0.brd, AT42QT2120-breakout-v0.sch]
2019-04-08 display fpc breakout
    [fpc-40-breakout.brd, fpc-40-breakout.sch]
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2019-04-13 update ATQ prototype board files
    [AT42QT2120-breakout-v0.brd, AT42QT2120-breakout-v0.sch, wheel.brd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]
2019-04-13 get rid of temp
    [Draft0.brd, Draft0.sch, VS1053 hardware.sch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]
2019-04-13 switch licenses to something we'd actually want when we eventually make this public (MIT)
2019-04-13 we're actually going to _not_ use a library for the wheel; just a regular part
2019-04-14 Power on/off changes + misc fixes
    Corrected the power on/off circuit (connected the top of the switch to the right net) and bumped up the resistor value so that it'll take ~6 seconds of the power button being held down to power off.
    The circuit should now match Figure 5 from [this](http://www.mosaic-industries.com/embedded-systems/microcontroller-projects/electronic-circuits/push-button-switch-turn-on/latching-toggle-power-switch).
    This fixes #1.
    Additionally, libraries used in the V0 files should match the rearranged folders.
    [V0.brd, V0.sch]
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2019-04-14 Add UVLO protection (using an APX809S-31SA)
    Closes #4
    [V0.brd, V0.sch]
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2019-04-14 Swap center buttons for 100Q (lower actuation force) variants
    [TL3315NF100Q.step, V0.brd, V0.sch]
2019-04-14 add missing esp32 capacitor values
    [V0.brd, V0.sch]
2019-04-14 Add charge detect back in, using up all our pins
    Closes #11
    [V0.brd, V0.sch]
2019-04-15 checkpoint: swapped resistors for the esp32/cp2102N/usb port, routed the usb port, and swapped the power source for the CP2102N (runs off the 3.3V regulator now; no sense in the device appearing on c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
    [V0.brd, V0.sch]
2019-04-15 board checkpoint
    [V0.brd, V0.sch]
2019-04-19 added pull ups to SD card
    [V0.brd, V0.sch]
2019-04-20 Swap resistors for the microSD Card
    10k pull-ups on everything appears to work (50k does not even though some of the guides say otherwise).
    Only 1-line MMC mode works so far, but there's still stuff to try.
    [V0.brd, V0.sch]
2019-04-20 Add an experimental card detect input to the ADC button circuit
    If this is problematic we can just remove/not populate the resistor for CARD_DETECT (R54). Just adding an input to the ADC and not the full diode + digital input line too because we can just poll the ADC when we have SD card errors to make sure we've got a card in place (I'd rather not add another one of those diodes).
    [V0.brd, V0.sch]
2019-04-21 Bridge IO0 and IO2 so that we can flash the board and use an SD Card
    From the message on sheet 1:
    IO2 is a strapping pin that allows the esp32 to enter download mode (iirc) - it's required to be pulled low when flashing the esp. Unforuntately, we have to use IO2 for the one usable SD/MMC interface on the esp32 (the other uses the same pins as flash).
    IO0 is also a strapping pin: it's connected to RTS on the CP2102N and is pulled low when we're flashing the board. So, if we tie IO0 to IO2, IO2 will be pulled down while flashing. This solves our problem!
    Unforunately this means that we can't use IO0 for anything else since it remains tied to IO2 (anything we do to IO0 will affect the SD/MMC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
    [V0.brd, V0.sch]
2019-04-22 Breakout board for an Adafruit microSD Card slot
    Got 4 line MMC to work. Turns out it had nothing to do with the breakout or the pull-up resistor values or the breadboard. Instead, the wires were just too long/crappy. 🤷
    This closes #7.
    [microsd-breakout.brd, microsd-breakout.sch]
2019-04-22 magnet positions: a guess
    the BOM is updated now too; gonna go with [these magnets](https://www.ebay.com/itm/1-100-Rare-Earth-Magnets-Neodymium-Round-Disk-Super-Strong-Large-Sizes-USA/122945482155), probably
    this closes #14
    [V0.brd, V0.sch]
2019-04-22 fix magnets (3mm _diameter_ - I hope)
    [V0.brd]
2019-04-22 checkpoint: 3.3V regulator
    [V0.brd, V0.sch]
2019-04-22 checkpoint: charge IC
    [V0.brd]
2019-04-22 checkpoint: vibration motor
    [V0.brd, V0.sch]
2019-04-22 checkpoint: power on/off
    [V0.brd, V0.sch]
2019-04-22 update Crystal library: don't put pin labels on the silkscreen
2019-04-23 checkpoint: ATQ, part 1
    [V0.brd]
2019-04-23 checkpoint: 1.8V regulator, first pass
    [V0.brd]
2019-04-23 checkpoint: sd card?
    [V0.brd, V0.sch]
2019-04-23 Add files via upload
    added button tester software, with threshold values
2019-04-24 backup done
    [Lab11 with Breakouts.brd, Lab11 with Breakouts.sch]
2019-04-25 backup board with fixes
    [Backup.brd, Backup.sch, V0.brd]
2019-04-30 swap VS1053 GPIO pull down resistors
    [V0.sch]
2019-04-30 add backup header pin block for the VS1053
    [V0.sch]
2019-04-30 VS1053 changes
    Switch back to bridging all the GPIO pins (the datasheet's sample connection diagram has it wired this way, so it'll hopefully not be an issue) and tie xRESET to V3P3 (pull-up) so that we can actually boot.
    The Adafruit VS1053 breakout schematic mentions that they tie xRESET to low (pull-down) to avoid transients (clicks) in the headphone outputs (as per [this](http://www.vlsi.fi/uploads/media/vs10XXan.pdf)) - making the MCU enable the VS1053 some time after system power up apparently helps mitigate this. Adafruit goes a step further and says that not doing this can "damage the earphones", but since we're pretty heavily pin starved we'll have to risk it.
    At this point we seem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
    [V0.sch]
2019-05-02 changes to backup
    [Backup.brd, Backup.sch]
2019-05-02 display prototype
    [fpc-40-breakout.brd, fpc-40-breakout.sch]
2019-05-02 most routing done
    [Backup.brd, Backup.sch]
2019-05-02 backup closer to done
    [Backup.brd]
2019-05-02 board closer
    [Backup.brd]
2019-05-02 housekeeping + checkpoint
    [kilo.brd, kilo.sch, pico.brd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]
2019-05-02 Redo the board for kilo, revision B (aka the backup board)
    Closes #17.
    Closes #18.
    Closes #19.
    Closes #20.
    Closes #21.
    Closes #22.
    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
    [kilo.brd, kilo.sch]
2019-05-03 checkpoint: pico is trudging along
    [pico.brd, pico.sch]
2019-05-03 checkpoint: mostly route complete (!)
    [pico.brd]
2019-05-03 checkpoint: route complete (!!)
    [pico.brd]
2019-05-03 checkpoint: drc, round 1
    [pico.brd]
2019-05-03 checkpoint: labels
    [pico.brd, pico.sch]
2019-05-03 checkpoint: drc, round 2
    [pico.brd]
2019-05-03 checkpoint: names and such
    [pico.brd]
2019-05-03 checkpoint: pico, mostly
    [pico.brd]
2019-05-03 start working on the wheel board, but really this is postponed until later
    [wheel.brd]
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2019-05-05 fix a small bug in the wheel generator
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2019-05-05 pico: checkpoint: an outdated wheel
    [wheel.brd]
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2019-05-05 pico: wheel board, basically complete
    [wheel.brd]
2019-05-05 pico: add some (bad) art
    [pico.brd]
2019-05-05 pico: DON'T PANIC
    (yes, I know - it should've been a dolphin or a mouse. gotta save something for revision B. and it's a cute fish.)
    [wheel.brd]
2019-05-05 pico: add some shiny wheel things and update pico's images
2019-05-05 pico: K -> k
    [pico.brd, pico.sch]
2019-05-07 simple-player: button debouncing, though messy, appears to work
    FreeRTOS seems gnarly
2019-05-07 simple-player: first pass at the display module
    this is a cleaned up version of Sameer's code; it's missing any kind of display initialization routine and is just generally untested
    [display.c]
2019-05-07 simple-player: sd card module seems to work (we can populate the track list)
2019-05-07 simple-player: Add ID3 (3.1 only) support!
    It detects when tracks have the 3.1 tags present and then goes and swaps out the name of those tracks with what it found.
    [sd_card.c]
